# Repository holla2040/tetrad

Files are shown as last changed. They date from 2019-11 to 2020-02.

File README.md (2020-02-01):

# hexad
A 4-axis ESP32 GRBL board 

Board
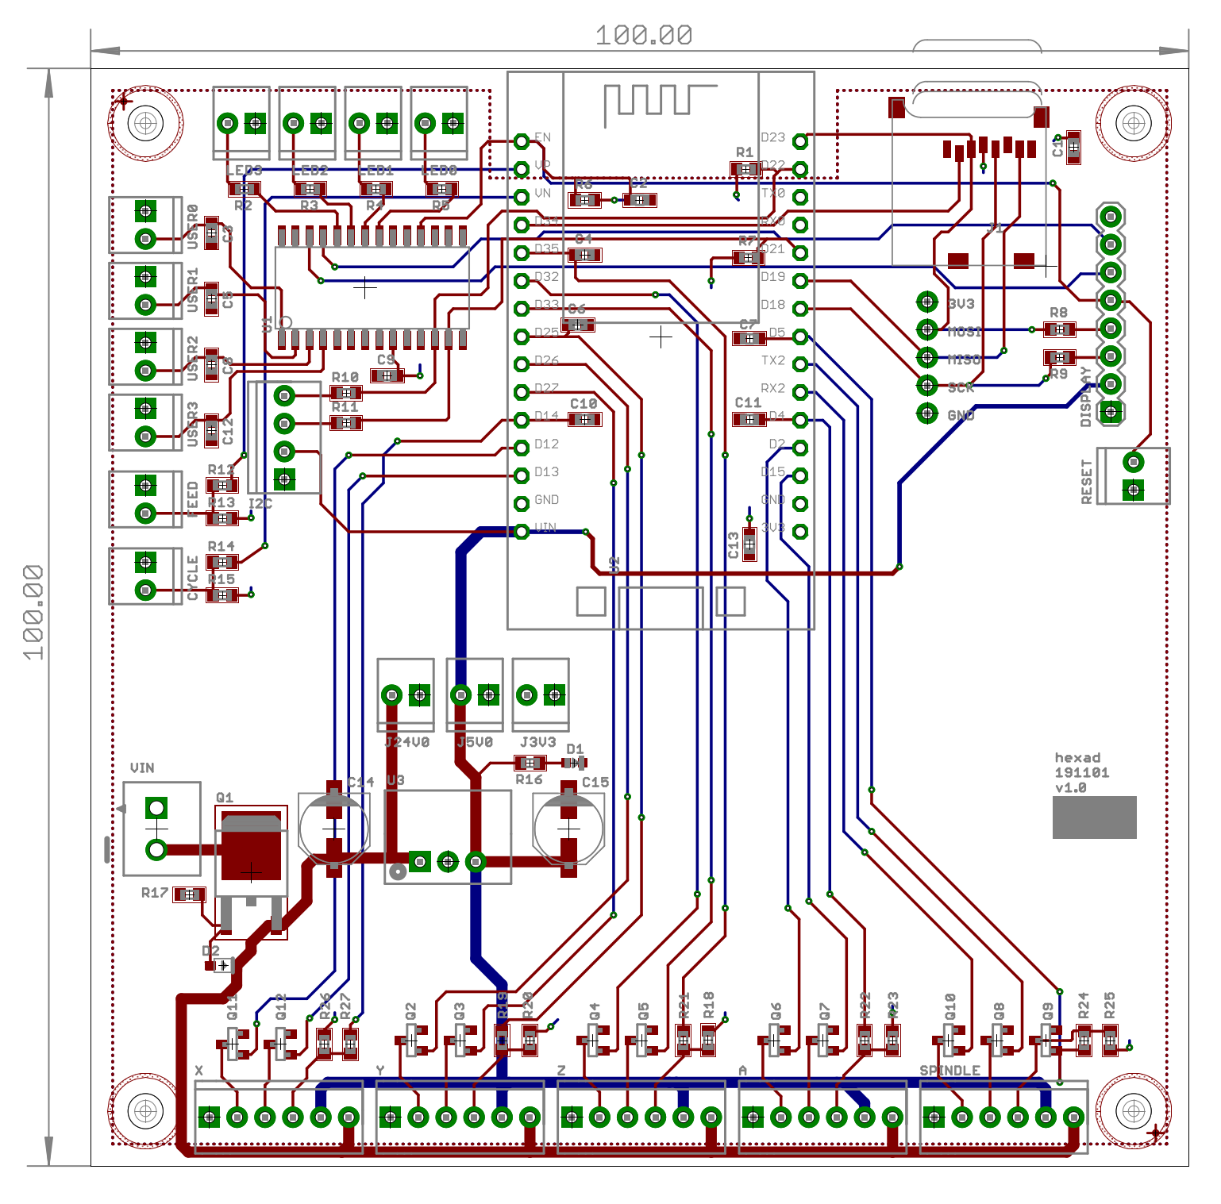
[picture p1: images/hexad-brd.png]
hexad board
    
    [Schematic](board/hexad-sch.pdf)

Requires
    [ESP32SSDP](https://github.com/luc-github/ESP32SSDP)

Compiling
    Select Board "ESP32 Dev Module"
    Flash Size "4MB (32Mb)"
    Partition Scheme "Minimal SPIFFS (1.9MB APP with OTA/190kB SPIFFS)"

    set options, like N_AXIS in config.h

----
Watch the video (https://youtu.be/7fjVDnm6PjQ)

Based on Dring's ESP32 GRBL port
 * [Grbl_ESP32 Development Board Version 3.1](http://www.buildlog.net/blog/2018/11/grbl_esp32-development-board-version-3-1/) 
 * [Source](https://github.com/bdring/Grbl_Esp32)
 * [Schematic](http://www.buildlog.net/blog/wp-content/uploads/2018/10/schm_esp32_cnc_test_v3p1.pdf)
 * [Wiki](https://github.com/bdring/Grbl_Esp32/wiki)

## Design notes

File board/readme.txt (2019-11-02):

This information, board files, assembly instructions and bill of
materials are company confidental.
Not for distribution.

board
    hexad

version
    v1.0

date
    191101

fudicials at
    x,y
    x,y

2 layer description
    2 layer board
        crc component cream
        plc component side silkscreen
        stc component side solder stop mask
        cmp component side copper
        sol solder side copper
        sts solder side solder stop mask
        pls solder side silkscreen
        crs solder cream

        drd drill data
        dri drill info
        gpi gerber info

2 layer stack up sequence
    top     x.cmp
    bottom  x.sol

contact info
    Craig Hollabaugh
    970 690 4911
    craig@hollabaugh.com

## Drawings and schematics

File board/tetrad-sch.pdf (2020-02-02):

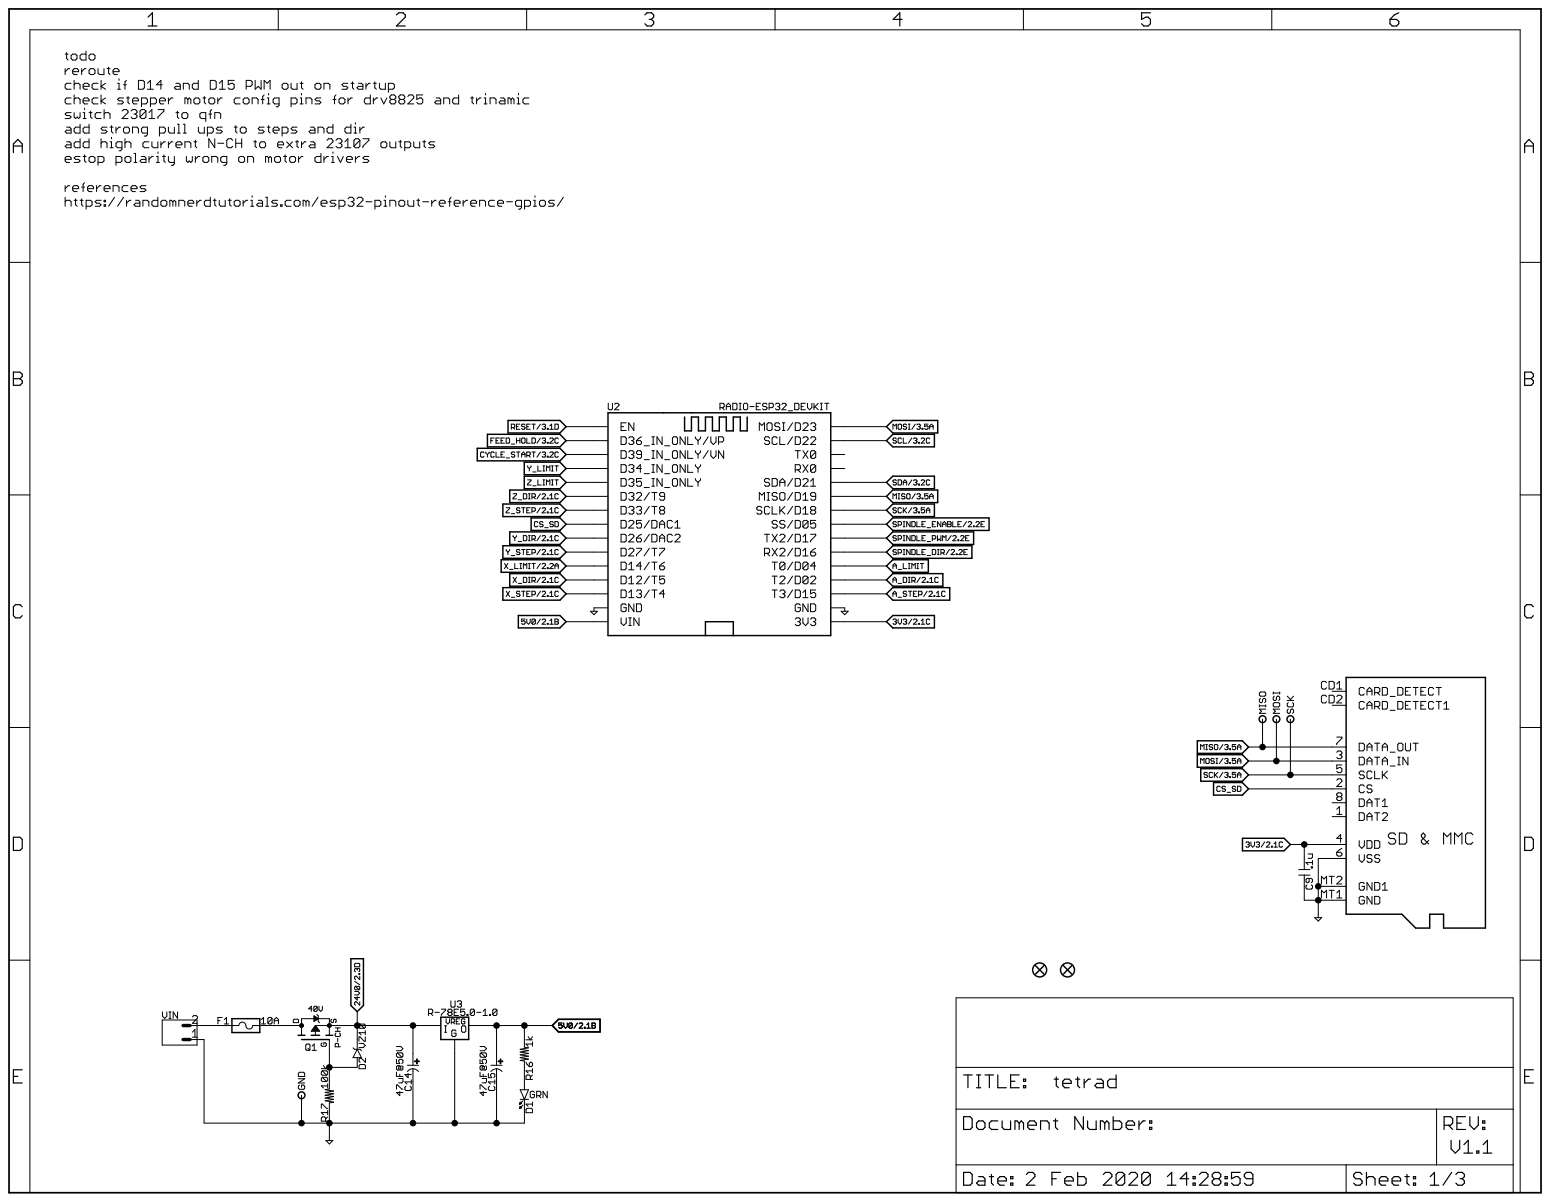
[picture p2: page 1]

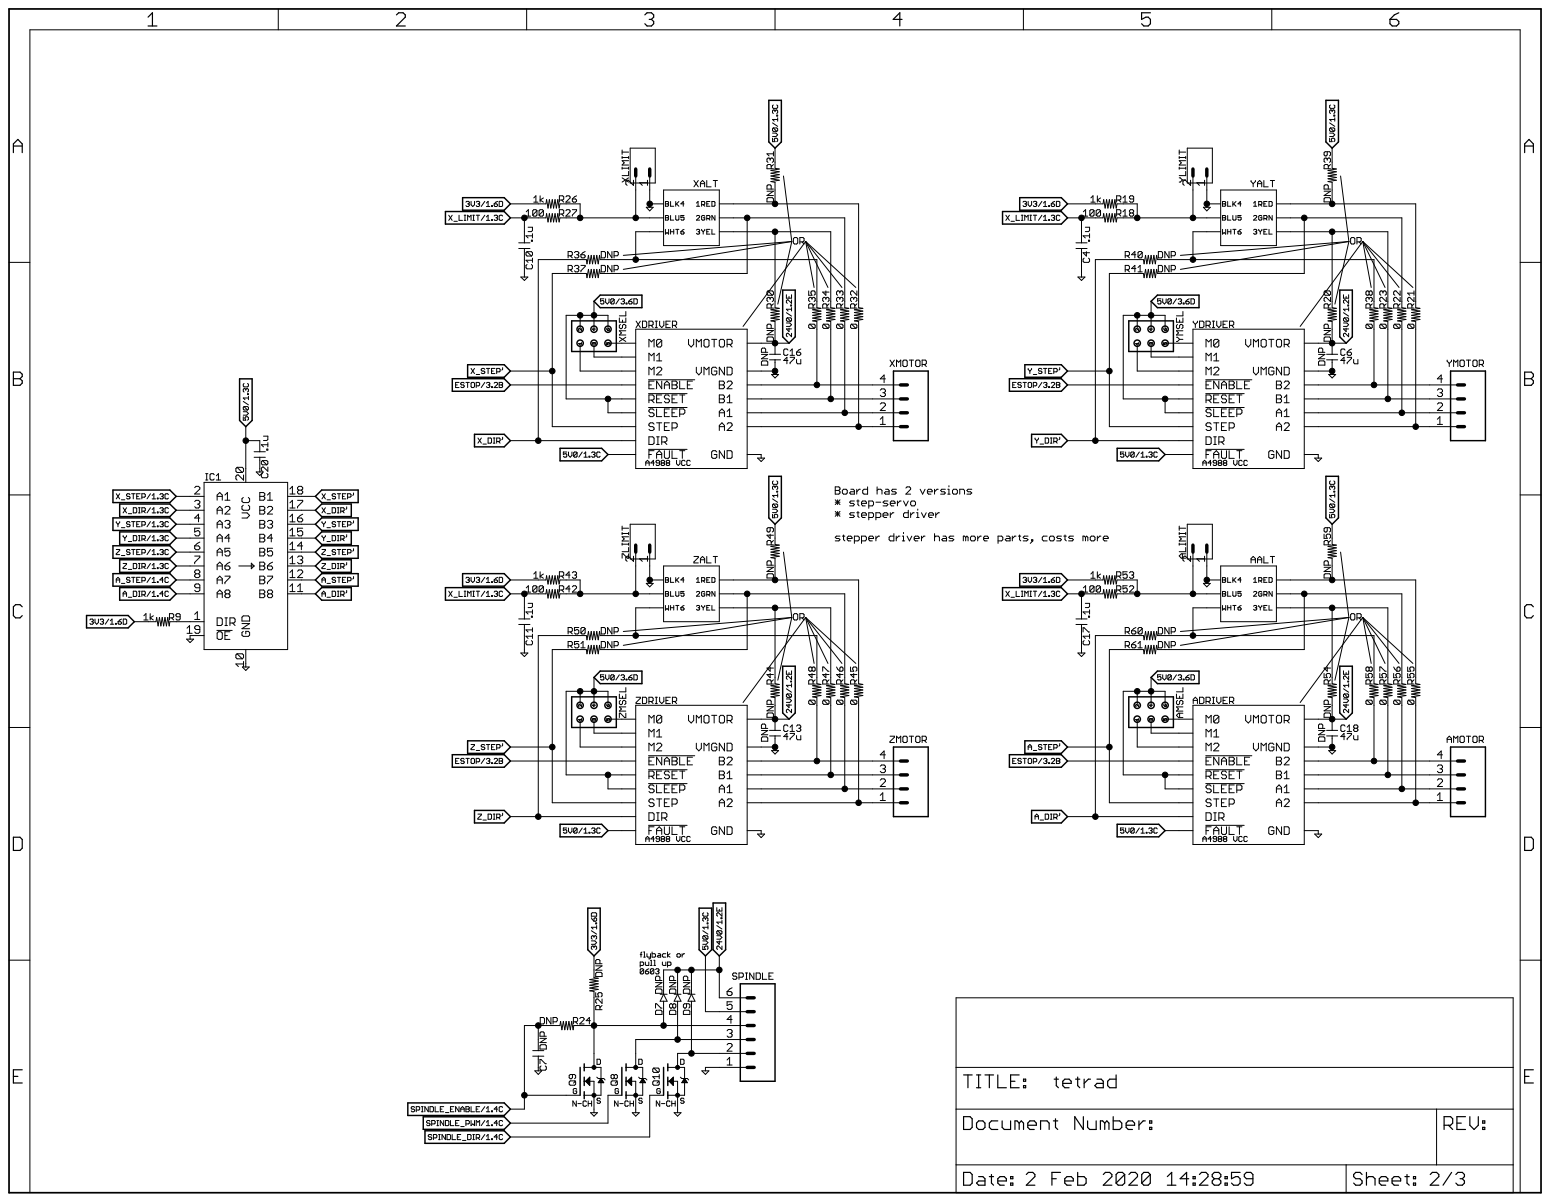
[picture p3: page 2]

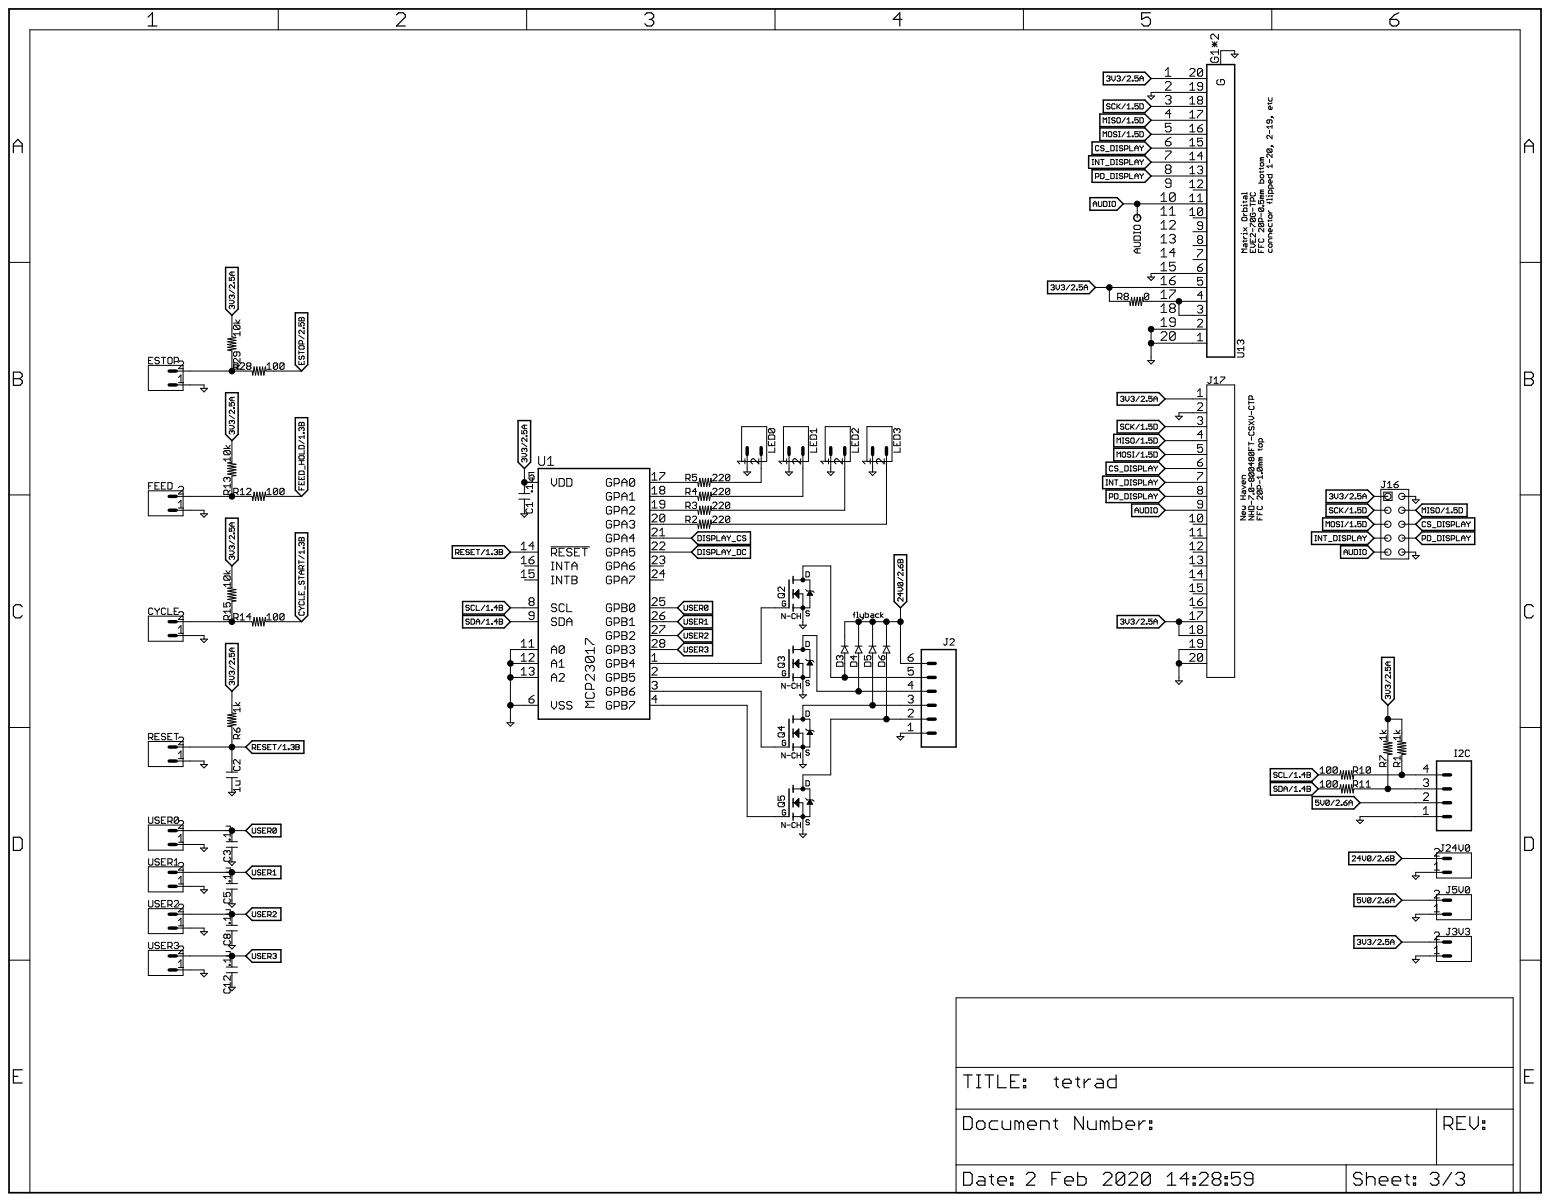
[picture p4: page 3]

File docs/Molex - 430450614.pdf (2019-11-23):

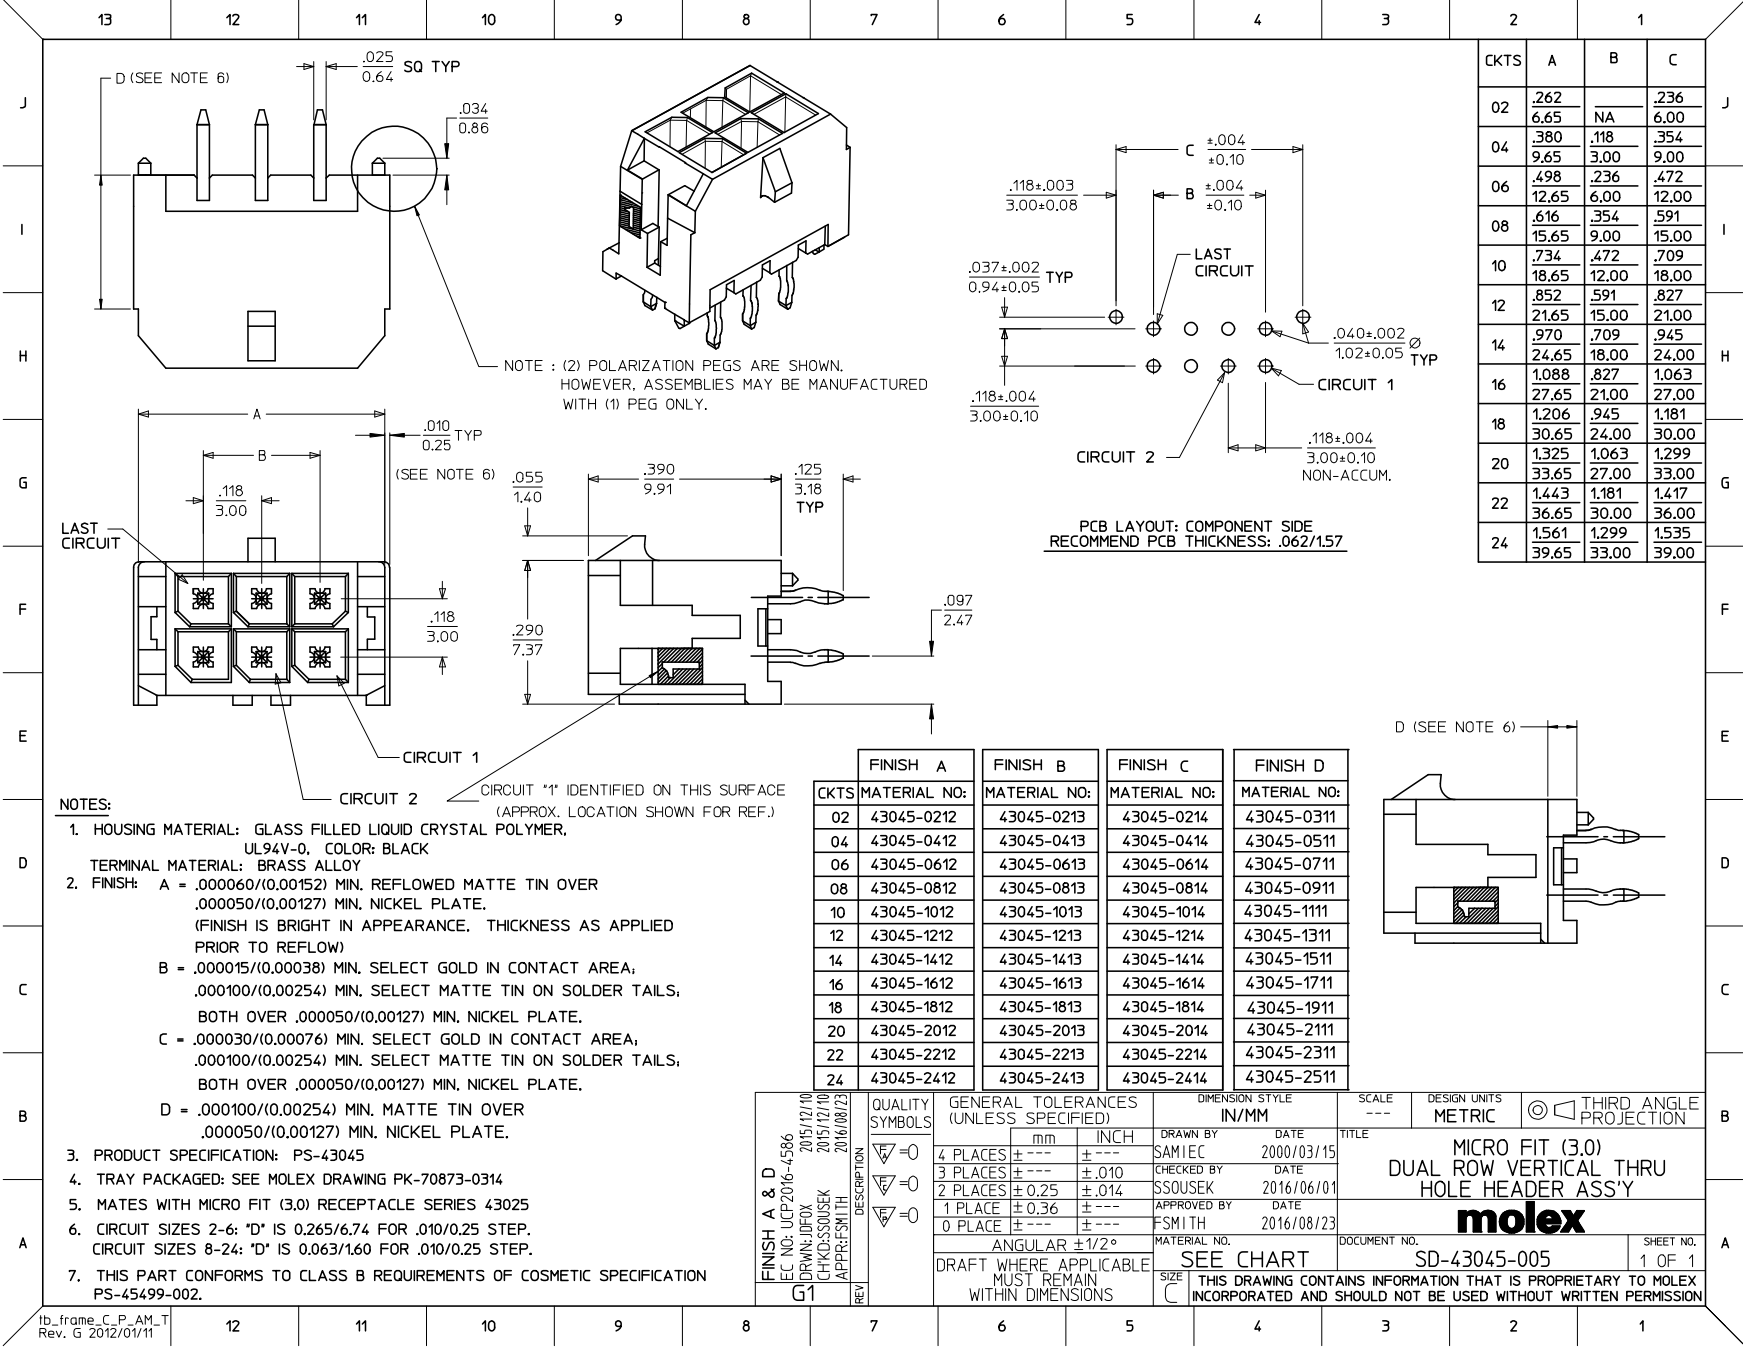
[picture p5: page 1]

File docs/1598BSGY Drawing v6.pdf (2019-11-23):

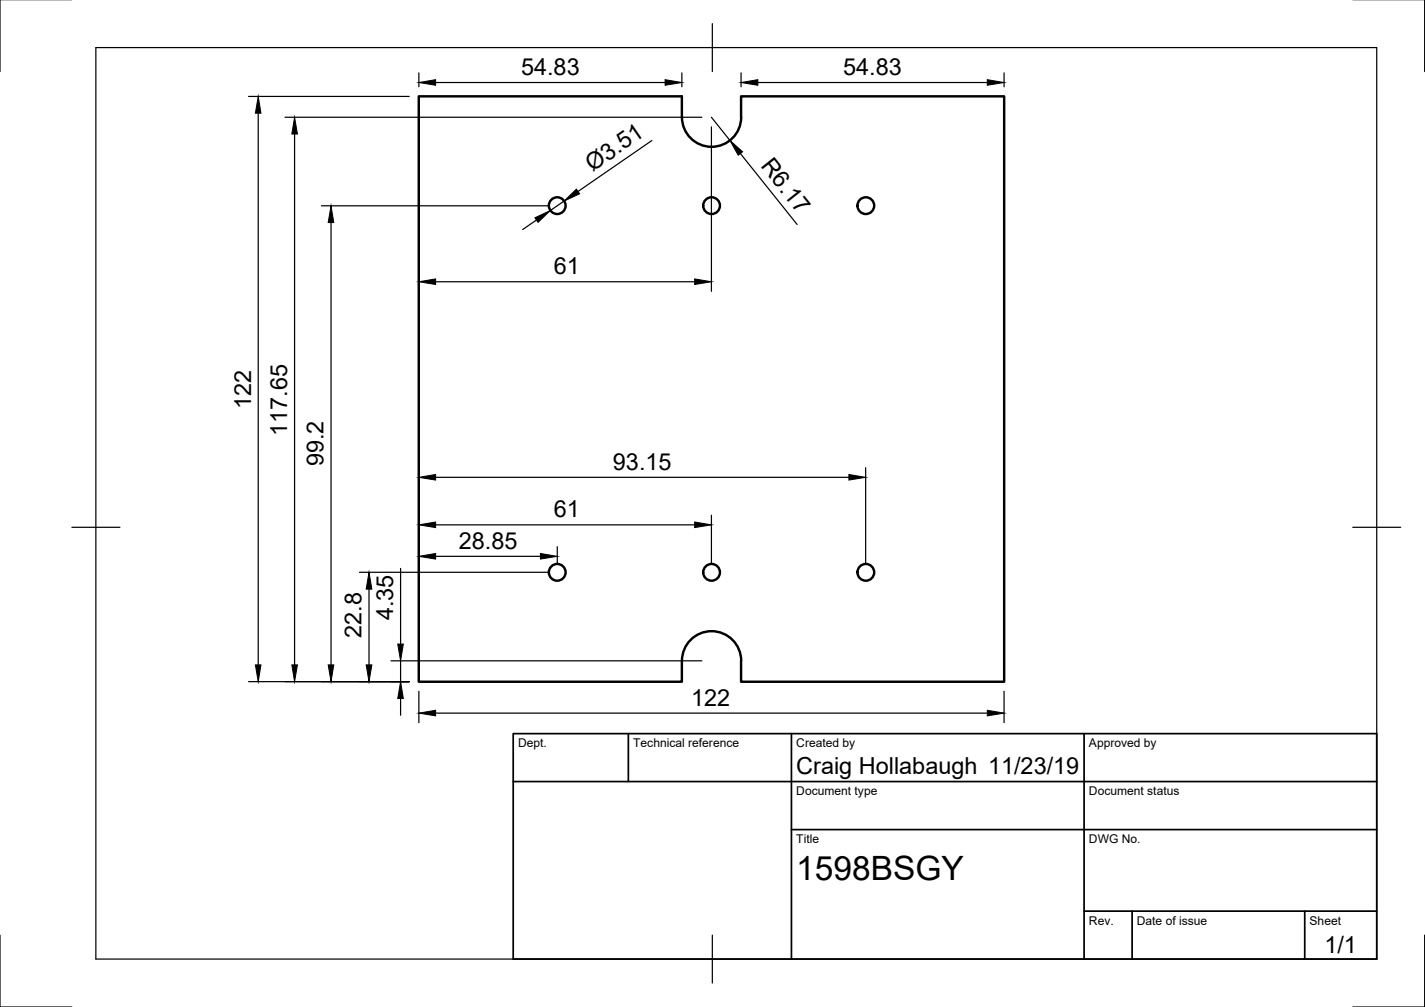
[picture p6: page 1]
Craig Hollabaugh 122

Dept. | Technical reference | Created by 11/23/19 | Approved by

Document type | Document status

Title 1598BSGY | DWG No.

Rev. | Date of issue | Sheet 1/1

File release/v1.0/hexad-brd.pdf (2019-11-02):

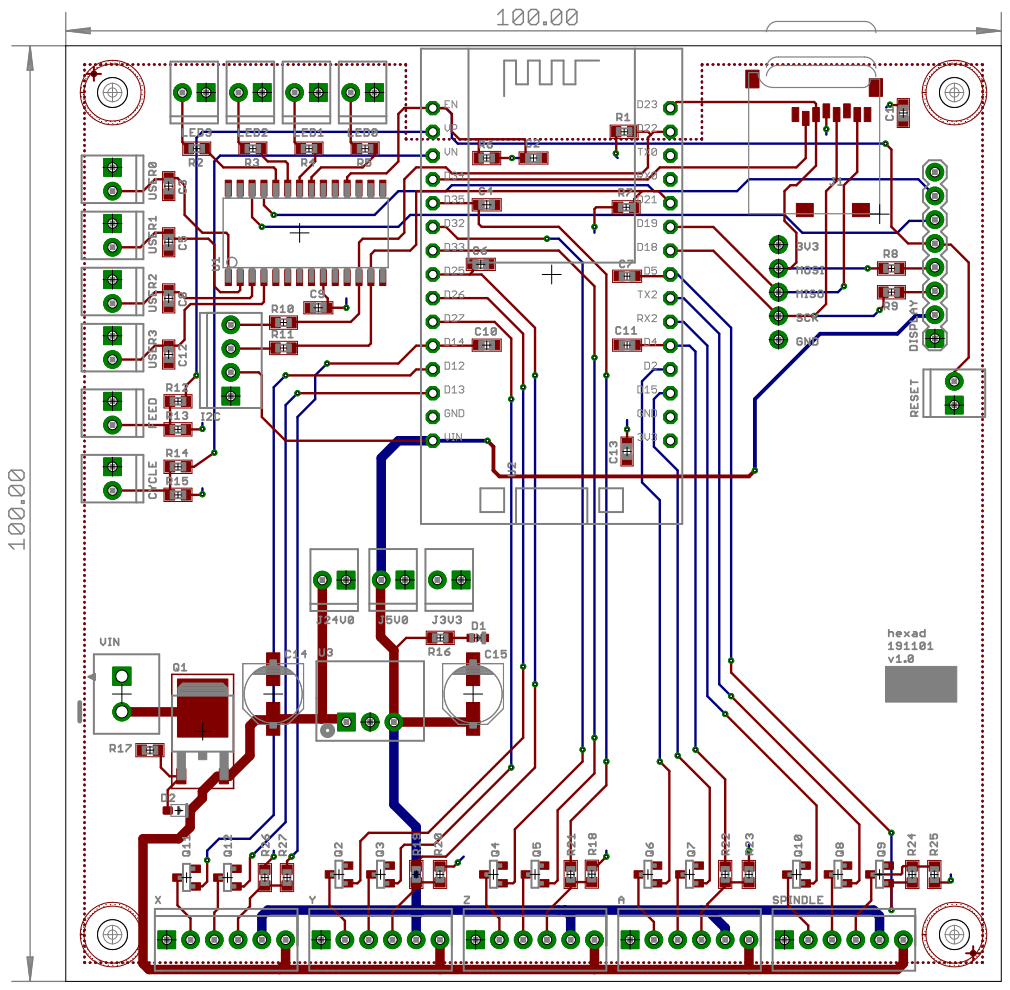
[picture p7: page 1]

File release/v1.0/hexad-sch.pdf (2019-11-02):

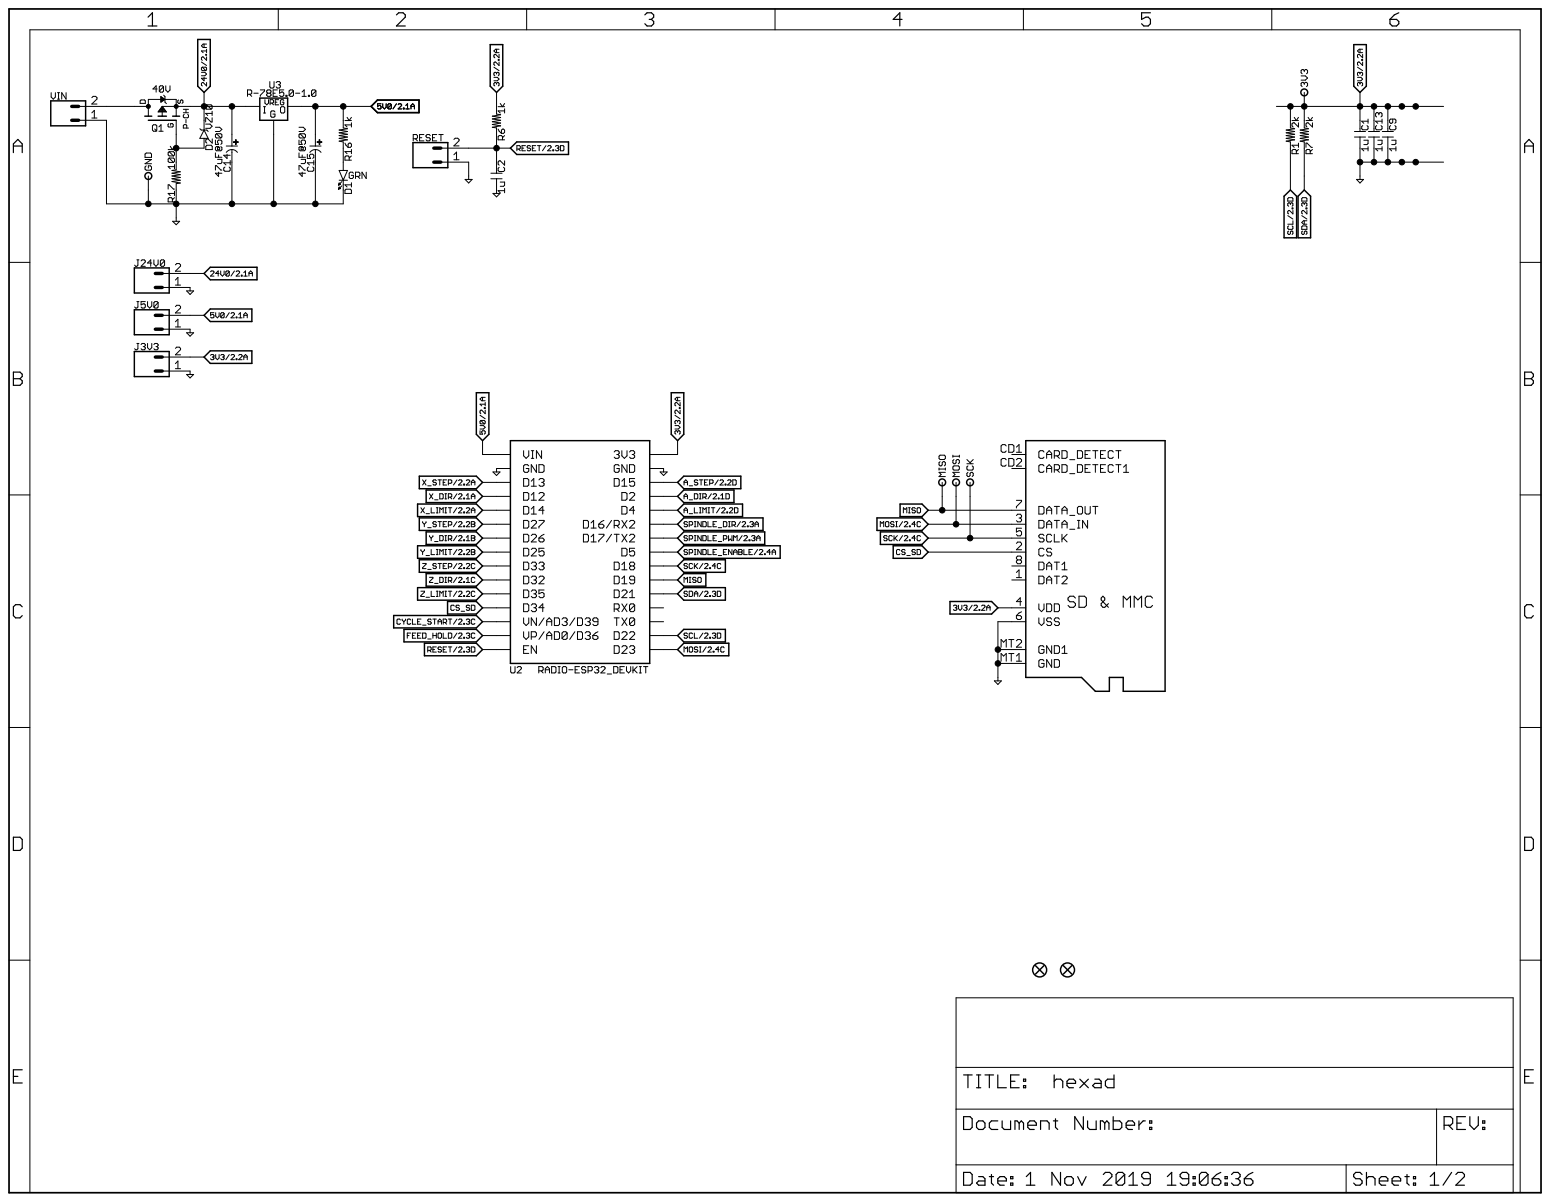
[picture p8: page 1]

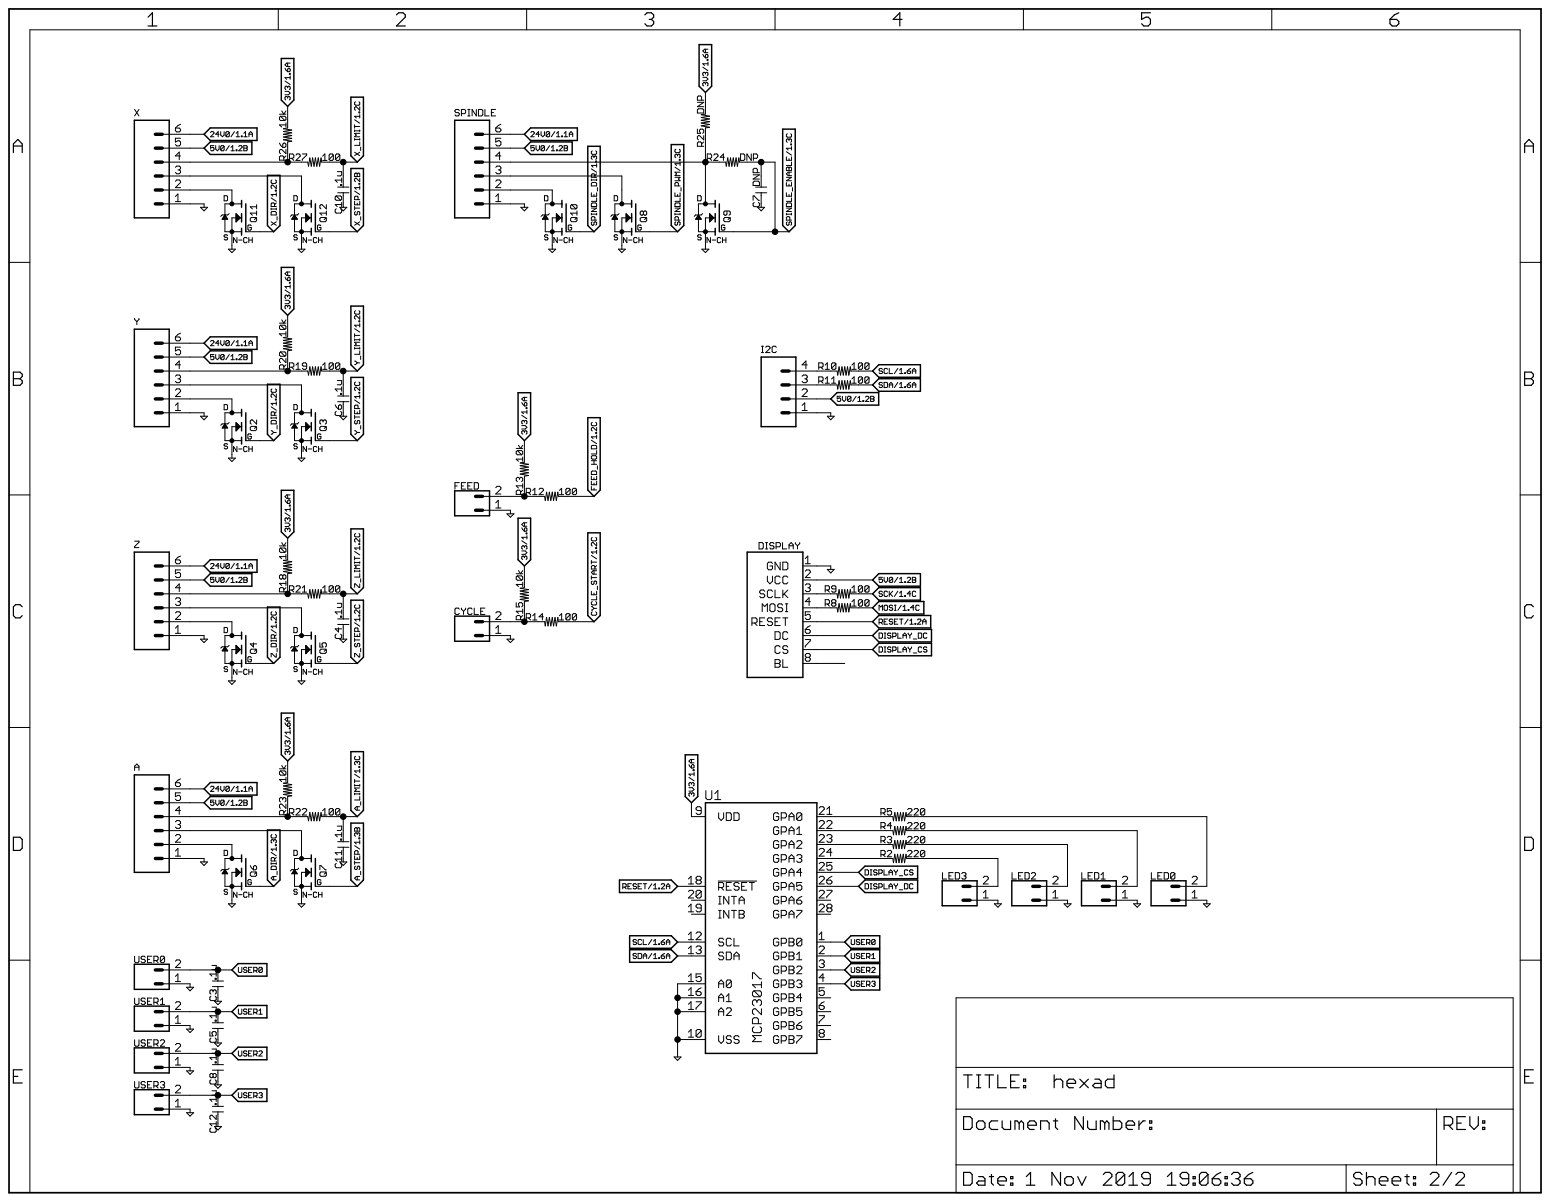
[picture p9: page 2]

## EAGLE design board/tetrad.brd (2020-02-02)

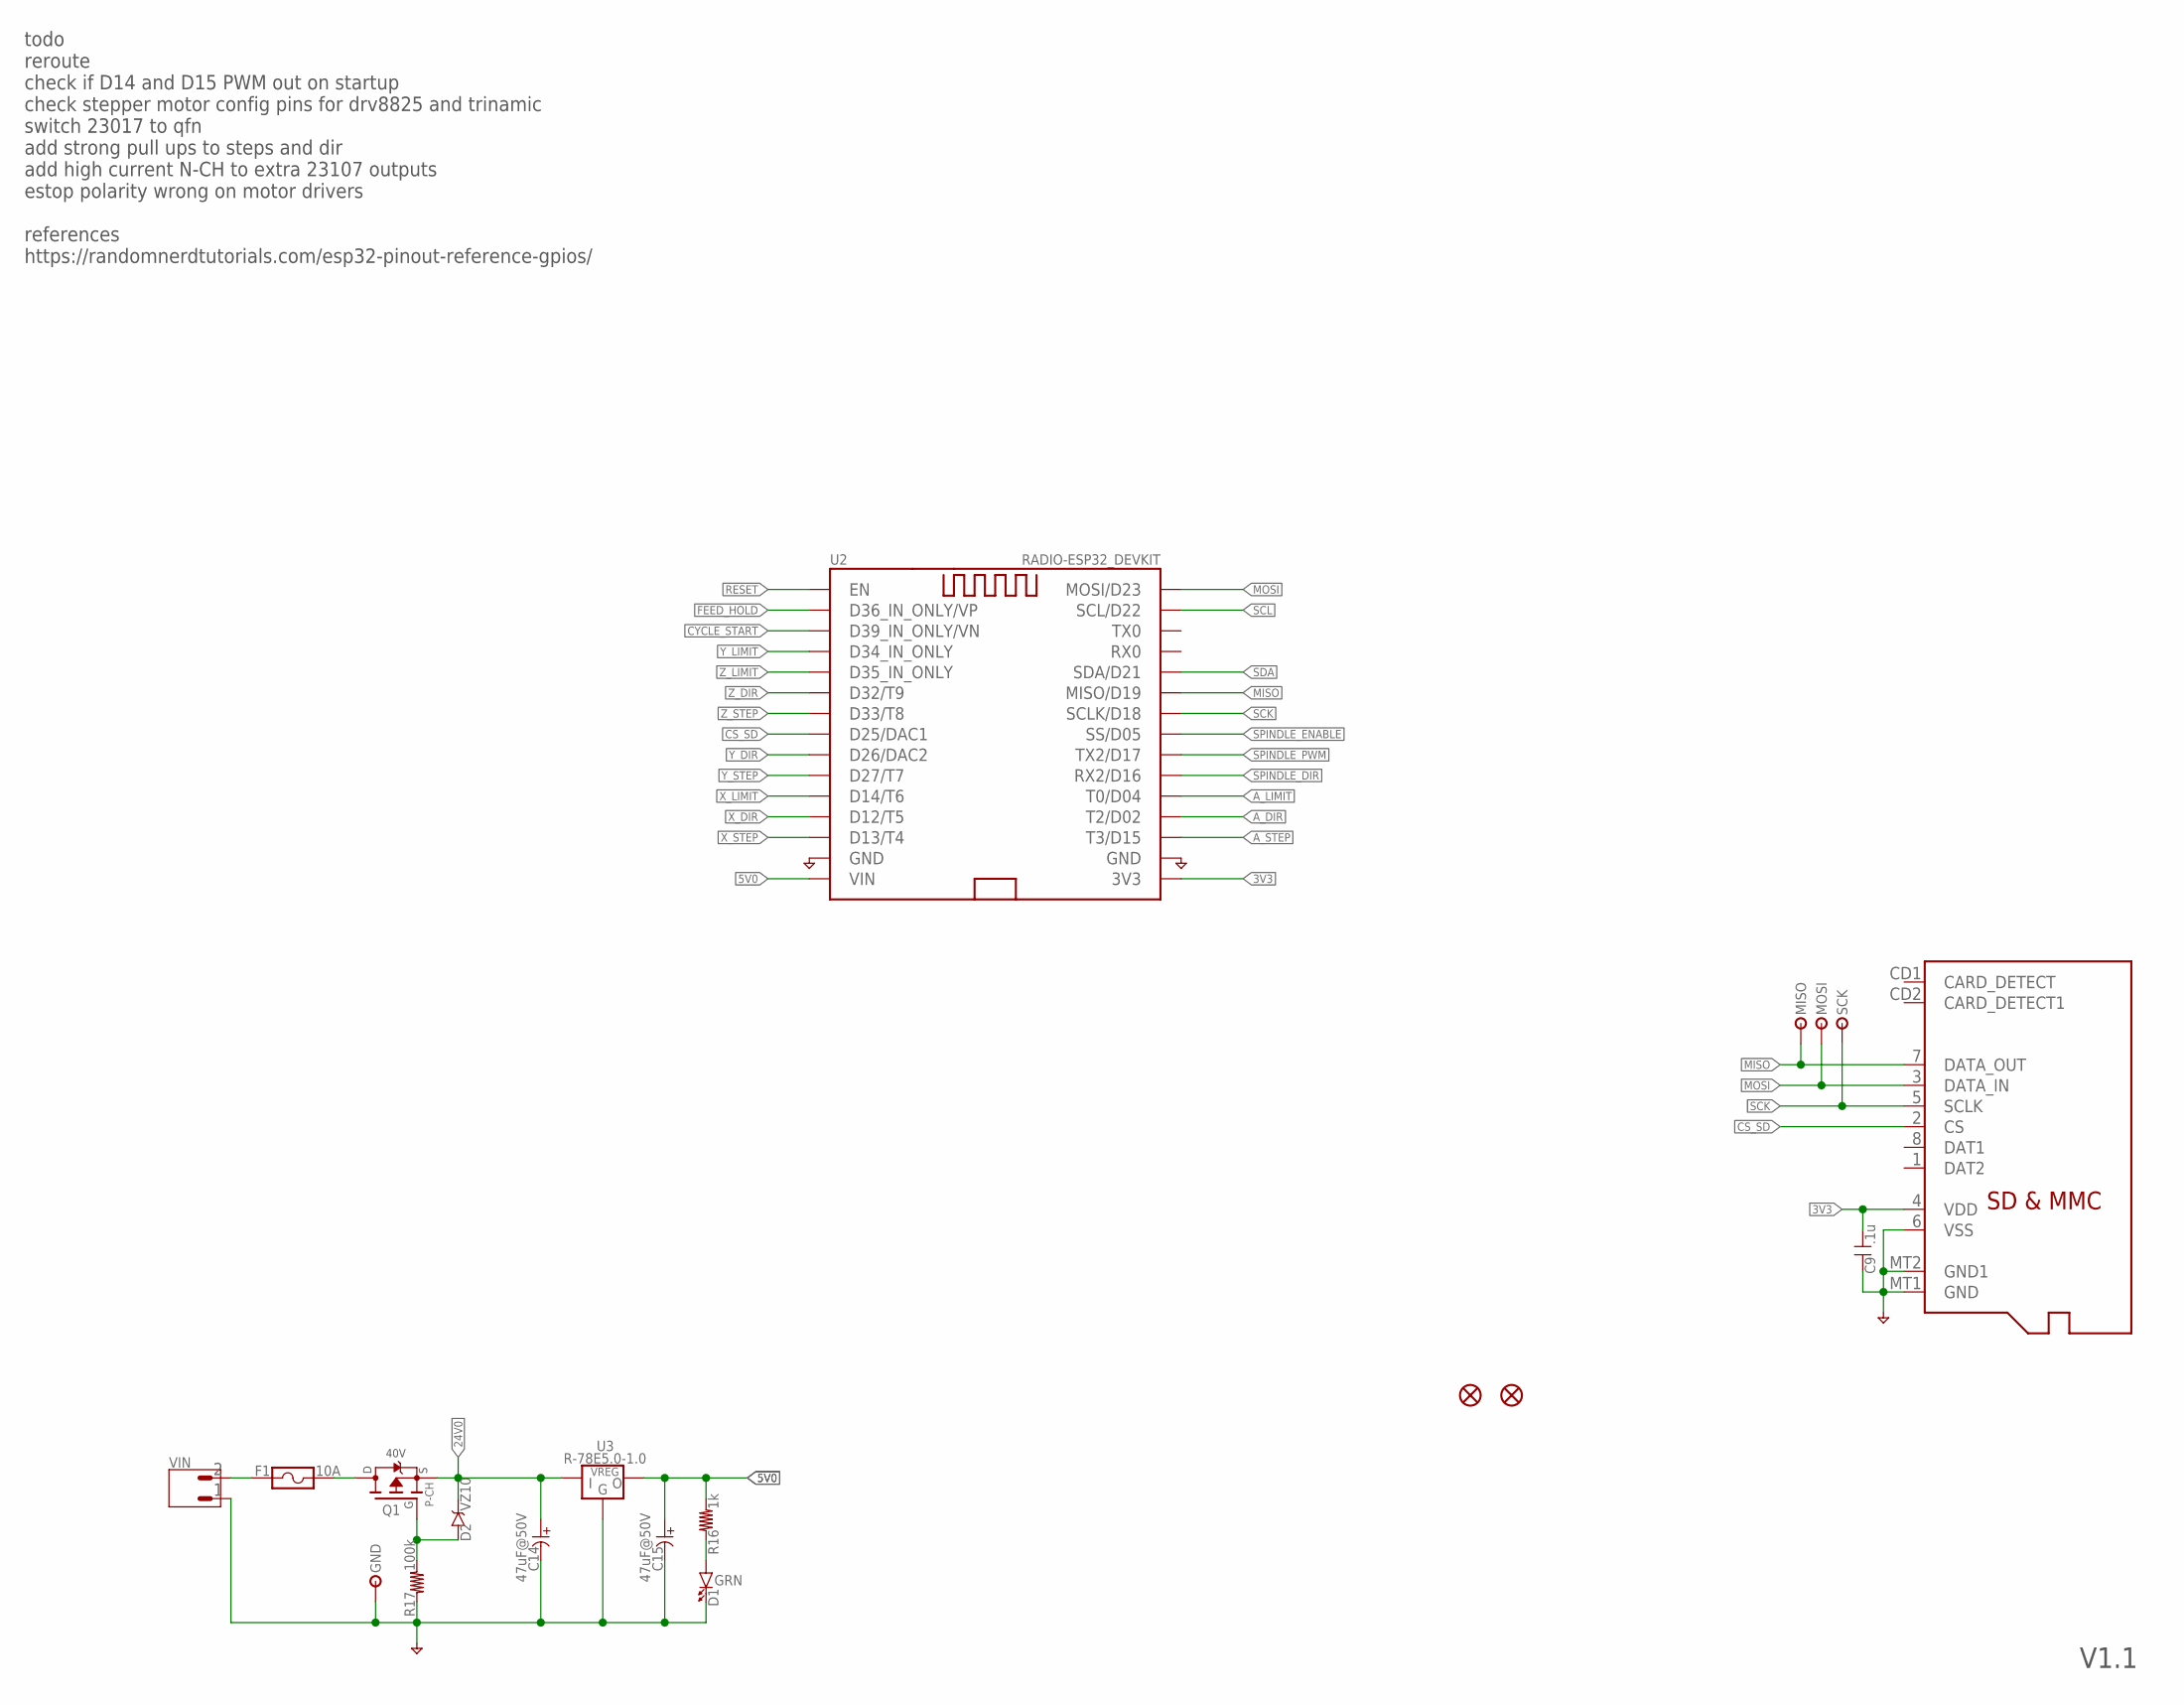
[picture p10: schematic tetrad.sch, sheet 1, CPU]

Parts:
C9: .1u; C-0603
C14, C15: 47uF@50V; C-E-6
D1: GRN; LED-0603
D2: VZ10; D-SOD323
F1: 10A; 3557-2
FID1, FID2: FIDUCIAL-MICRO
GND: TESTPOINTTHRU; TPTHRU
J1: CONN-MICROSD-2908-05WB-MG
MISO: TESTPOINTTHRU; TPTHRU
MOSI: TESTPOINTTHRU; TPTHRU
Q1: FET-PCH-TO252; TO252
R16: 1k; R-0603
R17: 100k; R-0603
SCK: TESTPOINTTHRU; TPTHRU
U2: RADIO-ESP32_DEVKIT; ESP32_DEVKIT
U3: R-78E5.0-1.0; VREG-SIP3
VIN: CONN-02-3.81MM-PLUGIN-SCREW; CONN-3.81MM-KF2EDG-2

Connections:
3V3: C9.1, J1.4 (VDD), U2.3V3; also elsewhere on the board
5V0: C15.+, R16.2, U2.VIN, U3.3 (VOUT); also elsewhere on the board
24V0: C14.+, D2.C, Q1.2 (S), U3.1 (VIN); also elsewhere on the board
A_DIR: U2.D2 (T2/D02); also elsewhere on the board
A_LIMIT: U2.D4 (T0/D04)
A_STEP: U2.D15 (T3/D15); also elsewhere on the board
CS_SD: J1.2 (CS), U2.D25 (D25/DAC1)
CYCLE_START: U2.VN (D39_IN_ONLY/VN); also elsewhere on the board
FEED_HOLD: U2.VP (D36_IN_ONLY/VP); also elsewhere on the board
GND: C9.2, C14.-, C15.-, D1.C, GND.1, J1.6 (VSS), J1.MT1 (GND), J1.MT2 (GND1), R17.1, U2.GND@1 (GND), U2.GND@2 (GND), U3.2 (GND), VIN.1; also elsewhere on the board
MISO: J1.7 (DATA_OUT), MISO.1, U2.D19 (MISO/D19); also elsewhere on the board
MOSI: J1.3 (DATA_IN), MOSI.1, U2.D23 (MOSI/D23); also elsewhere on the board
unnamed: F1.1@1, F1.1@2, VIN.2
unnamed: D2.A, Q1.1 (G), R17.2
unnamed: F1.2@1, F1.2@2, Q1.3 (D)
unnamed: D1.A, R16.1
RESET: U2.EN; also elsewhere on the board
SCK: J1.5 (SCLK), SCK.1, U2.D18 (SCLK/D18); also elsewhere on the board
SCL: U2.D22 (SCL/D22); also elsewhere on the board
SDA: U2.D21 (SDA/D21); also elsewhere on the board
SPINDLE_DIR: U2.RX2 (RX2/D16); also elsewhere on the board
SPINDLE_ENABLE: U2.D5 (SS/D05); also elsewhere on the board
SPINDLE_PWM: U2.TX2 (TX2/D17); also elsewhere on the board
X_DIR: U2.D12 (D12/T5); also elsewhere on the board
X_LIMIT: U2.D14 (D14/T6); also elsewhere on the board
X_STEP: U2.D13 (D13/T4); also elsewhere on the board
Y_DIR: U2.D26 (D26/DAC2); also elsewhere on the board
Y_LIMIT: U2.D34 (D34_IN_ONLY)
Y_STEP: U2.D27 (D27/T7); also elsewhere on the board
Z_DIR: U2.D32 (D32/T9); also elsewhere on the board
Z_LIMIT: U2.D35 (D35_IN_ONLY)
Z_STEP: U2.D33 (D33/T8); also elsewhere on the board

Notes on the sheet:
todo reroute check if D14 and D15 PWM out on startup check stepper motor config pins for drv8825 and trinamic switch 23017 to qfn add strong pull ups to steps and dir add high current N-CH to extra 23107 outputs estop polarity wrong on motor drivers references https://randomnerdtutorials.com/esp32-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
40V
V1.1

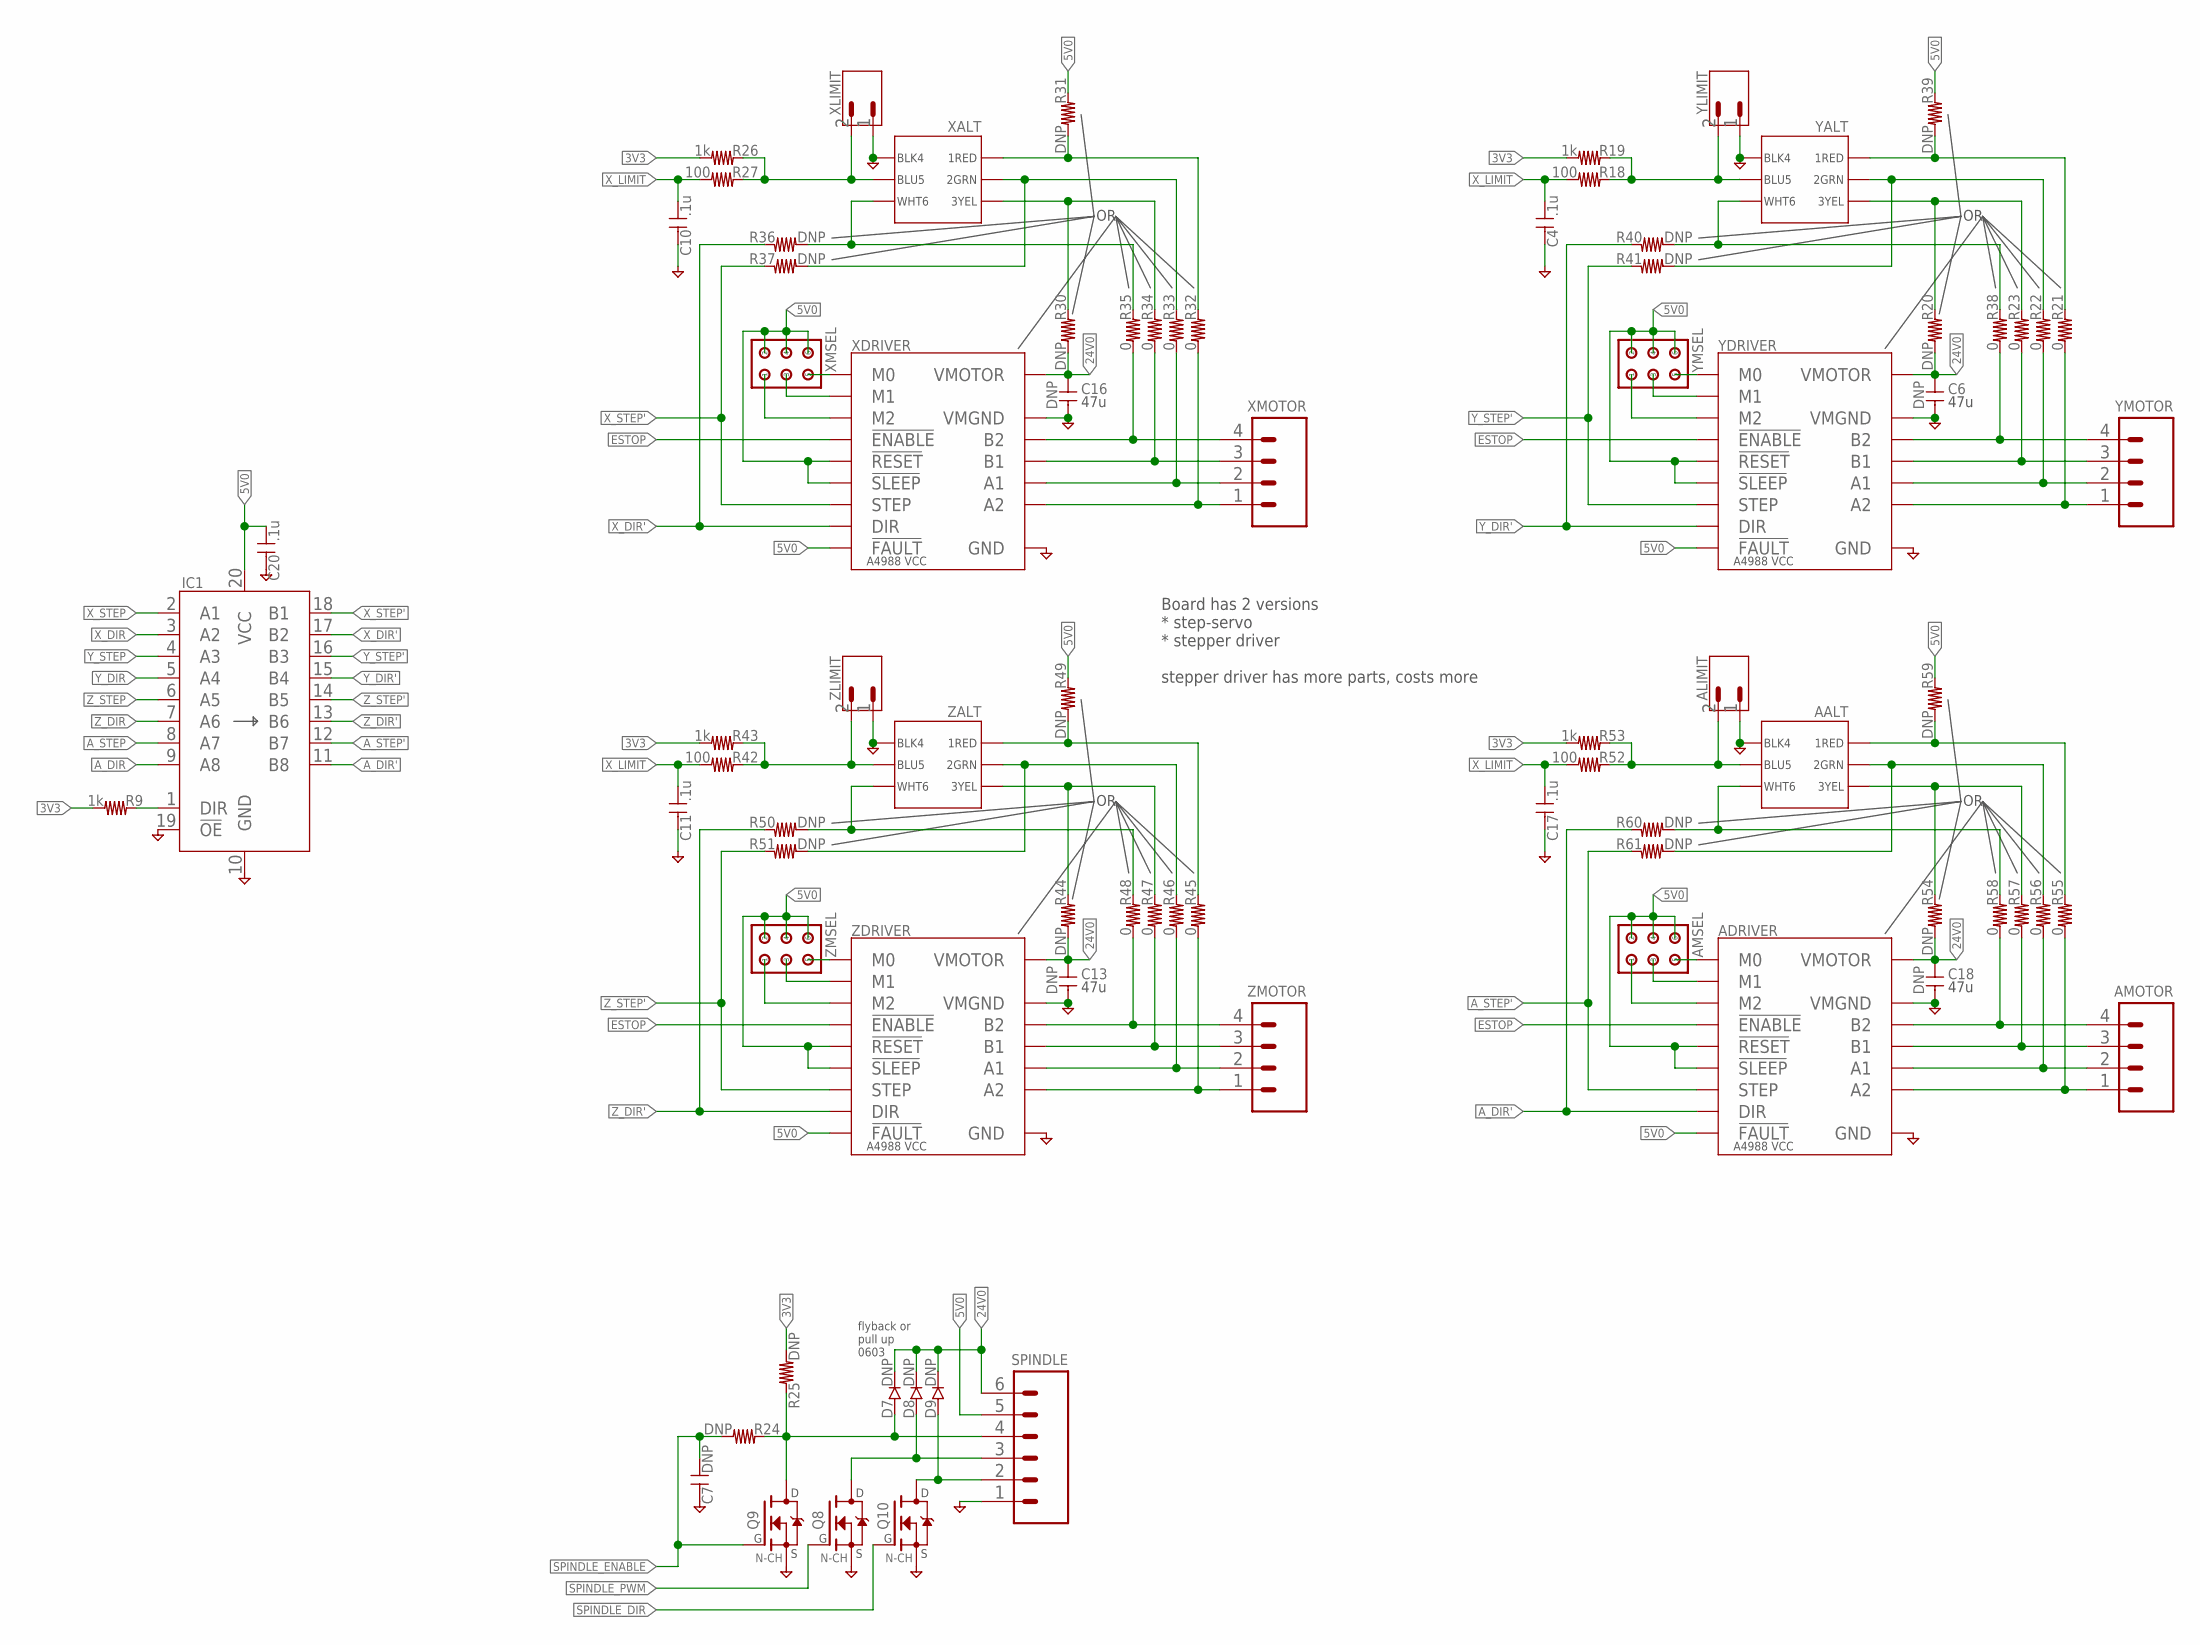
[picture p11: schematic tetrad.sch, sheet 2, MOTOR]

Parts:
AALT: CONN-03X2-MICROFIT-TH-SMD; MOLEX_430450614_430450615
ADRIVER: BOARD-DRV8825-CARRIER-TH-SMD; IC_DRV8825_CARRIER_TH_SMD
ALIMIT: CONN-02-.100-VERT-HEADER; CONN-.100-2
AMOTOR: CONN-04-.100-VERT-HEADER; CONN-.100-4
AMSEL: CONN-03X2-RH; AMPHENOL_95278-101A06LF
C4, C10, C11, C17, C20: .1u; C-0603
C6, C13, C16, C18: DNP; C-1206
C7: DNP; C-0603
D7, D8, D9: DNP; D-SOD523
IC1: 74LS245DW; SO20W
Q8, Q9, Q10: FET-NCH-SOT23; SOT23-3
R9, R19, R26, R43, R53: 1k; R-0603
R18, R27, R42, R52: 100; R-0603
R20, R24, R25, R30, R31, R36, R37, R39, R40, R41, R44, R49, R50, R51, R54, R59, R60, R61: DNP; R-0603
R21, R22, R23, R32, R33, R34, R35, R38, R45, R46, R47, R48, R55, R56, R57, R58: 0; R-0603
SPINDLE: CONN-06-.100-VERT-HEADER; CONN-.100-6
XALT: CONN-03X2-MICROFIT-TH-SMD; MOLEX_430450614_430450615
XDRIVER: BOARD-DRV8825-CARRIER-TH-SMD; IC_DRV8825_CARRIER_TH_SMD
XLIMIT: CONN-02-.100-VERT-HEADER; CONN-.100-2
XMOTOR: CONN-04-.100-VERT-HEADER; CONN-.100-4
XMSEL: CONN-03X2-RH; AMPHENOL_95278-101A06LF
YALT: CONN-03X2-MICROFIT-TH-SMD; MOLEX_430450614_430450615
YDRIVER: BOARD-DRV8825-CARRIER-TH-SMD; IC_DRV8825_CARRIER_TH_SMD
YLIMIT: CONN-02-.100-VERT-HEADER; CONN-.100-2
YMOTOR: CONN-04-.100-VERT-HEADER; CONN-.100-4
YMSEL: CONN-03X2-RH; AMPHENOL_95278-101A06LF
ZALT: CONN-03X2-MICROFIT-TH-SMD; MOLEX_430450614_430450615
ZDRIVER: BOARD-DRV8825-CARRIER-TH-SMD; IC_DRV8825_CARRIER_TH_SMD
ZLIMIT: CONN-02-.100-VERT-HEADER; CONN-.100-2
ZMOTOR: CONN-04-.100-VERT-HEADER; CONN-.100-4
ZMSEL: CONN-03X2-RH; AMPHENOL_95278-101A06LF

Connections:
3V3: R9.2, R19.2, R25.2, R26.2, R43.2, R53.2; also elsewhere on the board
5V0: ADRIVER.5 (!RESET), ADRIVER.5_ (!RESET), ADRIVER.6 (!SLEEP), ADRIVER.6_ (!SLEEP), ADRIVER.10 (!FAULT), ADRIVER.10_ (!FAULT), AMSEL.2, AMSEL.4, AMSEL.6, C20.1, IC1.20 (VCC), R31.1, R39.1, R49.1, R59.1, SPINDLE.5, XDRIVER.5 (!RESET), XDRIVER.5_ (!RESET), XDRIVER.6 (!SLEEP), XDRIVER.6_ (!SLEEP), XDRIVER.10 (!FAULT), XDRIVER.10_ (!FAULT), XMSEL.2, XMSEL.4, XMSEL.6, YDRIVER.5 (!RESET), YDRIVER.5_ (!RESET), YDRIVER.6 (!SLEEP), YDRIVER.6_ (!SLEEP), YDRIVER.10 (!FAULT), YDRIVER.10_ (!FAULT), YMSEL.2, YMSEL.4, YMSEL.6, ZDRIVER.5 (!RESET), ZDRIVER.5_ (!RESET), ZDRIVER.6 (!SLEEP), ZDRIVER.6_ (!SLEEP), ZDRIVER.10 (!FAULT), ZDRIVER.10_ (!FAULT), ZMSEL.2, ZMSEL.4, ZMSEL.6; also elsewhere on the board
24V0: ADRIVER.16 (VMOTOR), ADRIVER.16_ (VMOTOR), C6.1, C13.1, C16.1, C18.1, D7.C, D8.C, D9.C, R20.2, R30.2, R44.2, R54.2, SPINDLE.6, XDRIVER.16 (VMOTOR), XDRIVER.16_ (VMOTOR), YDRIVER.16 (VMOTOR), YDRIVER.16_ (VMOTOR), ZDRIVER.16 (VMOTOR), ZDRIVER.16_ (VMOTOR); also elsewhere on the board
A_DIR: IC1.9 (A8); also elsewhere on the board
A_DIR': ADRIVER.8 (DIR), ADRIVER.8_ (DIR), IC1.11 (B8), R60.1
A_STEP: IC1.8 (A7); also elsewhere on the board
A_STEP': ADRIVER.7 (STEP), ADRIVER.7_ (STEP), IC1.12 (B7), R61.1
ESTOP: ADRIVER.1 (!ENABLE), ADRIVER.1_ (!ENABLE), XDRIVER.1 (!ENABLE), XDRIVER.1_ (!ENABLE), YDRIVER.1 (!ENABLE), YDRIVER.1_ (!ENABLE), ZDRIVER.1 (!ENABLE), ZDRIVER.1_ (!ENABLE); also elsewhere on the board
GND: AALT.4, AALT.4_ (4), ADRIVER.9 (GND), ADRIVER.9_ (GND), ADRIVER.15 (VMGND), ADRIVER.15_ (VMGND), ALIMIT.1, C4.2, C6.2, C7.2, C10.2, C11.2, C13.2, C16.2, C17.2, C18.2, C20.2, IC1.10 (GND), IC1.19 (!OE), Q8.2 (S), Q9.2 (S), Q10.2 (S), SPINDLE.1, XALT.4, XALT.4_ (4), XDRIVER.9 (GND), XDRIVER.9_ (GND), XDRIVER.15 (VMGND), XDRIVER.15_ (VMGND), XLIMIT.1, YALT.4, YALT.4_ (4), YDRIVER.9 (GND), YDRIVER.9_ (GND), YDRIVER.15 (VMGND), YDRIVER.15_ (VMGND), YLIMIT.1, ZALT.4, ZALT.4_ (4), ZDRIVER.9 (GND), ZDRIVER.9_ (GND), ZDRIVER.15 (VMGND), ZDRIVER.15_ (VMGND), ZLIMIT.1; also elsewhere on the board
unnamed: R30.1, R34.1, XALT.3, XALT.3_ (3)
unnamed: IC1.1 (DIR), R9.1
unnamed: R31.2, R32.1, XALT.1, XALT.1_ (1)
unnamed: R21.2, YDRIVER.11 (A2), YDRIVER.11_ (A2), YMOTOR.1
unnamed: YDRIVER.2 (M0), YDRIVER.2_ (M0), YMSEL.5
unnamed: YDRIVER.3 (M1), YDRIVER.3_ (M1), YMSEL.3
unnamed: YDRIVER.4 (M2), YDRIVER.4_ (M2), YMSEL.1
unnamed: R22.2, YDRIVER.12 (A1), YDRIVER.12_ (A1), YMOTOR.2
unnamed: R23.2, YDRIVER.13 (B1), YDRIVER.13_ (B1), YMOTOR.3
unnamed: D7.A, Q9.3 (D), R24.1, R25.1, SPINDLE.4
unnamed: D9.A, Q10.3 (D), SPINDLE.2
unnamed: R38.2, YDRIVER.14 (B2), YDRIVER.14_ (B2), YMOTOR.4
unnamed: R32.2, XDRIVER.11 (A2), XDRIVER.11_ (A2), XMOTOR.1
unnamed: R18.1, R19.1, YALT.5, YALT.5_ (5), YLIMIT.2
unnamed: XDRIVER.2 (M0), XDRIVER.2_ (M0), XMSEL.5
unnamed: XDRIVER.3 (M1), XDRIVER.3_ (M1), XMSEL.3
unnamed: XDRIVER.4 (M2), XDRIVER.4_ (M2), XMSEL.1
unnamed: R38.1, R40.2, YALT.6, YALT.6_ (6)
unnamed: R21.1, R39.2, YALT.1, YALT.1_ (1)
unnamed: R20.1, R23.1, YALT.3, YALT.3_ (3)
unnamed: R45.2, ZDRIVER.11 (A2), ZDRIVER.11_ (A2), ZMOTOR.1
unnamed: ZDRIVER.2 (M0), ZDRIVER.2_ (M0), ZMSEL.5
unnamed: ZDRIVER.3 (M1), ZDRIVER.3_ (M1), ZMSEL.3
unnamed: ZDRIVER.4 (M2), ZDRIVER.4_ (M2), ZMSEL.1
unnamed: R46.2, ZDRIVER.12 (A1), ZDRIVER.12_ (A1), ZMOTOR.2
unnamed: R47.2, ZDRIVER.13 (B1), ZDRIVER.13_ (B1), ZMOTOR.3
unnamed: R48.2, ZDRIVER.14 (B2), ZDRIVER.14_ (B2), ZMOTOR.4
unnamed: R42.1, R43.1, ZALT.5, ZALT.5_ (5), ZLIMIT.2
unnamed: R48.1, R50.2, ZALT.6, ZALT.6_ (6)
unnamed: R45.1, R49.2, ZALT.1, ZALT.1_ (1)
unnamed: R44.1, R47.1, ZALT.3, ZALT.3_ (3)
unnamed: ADRIVER.11 (A2), ADRIVER.11_ (A2), AMOTOR.1, R55.2
unnamed: R35.2, XDRIVER.14 (B2), XDRIVER.14_ (B2), XMOTOR.4
unnamed: R26.1, R27.1, XALT.5, XALT.5_ (5), XLIMIT.2
unnamed: ADRIVER.2 (M0), ADRIVER.2_ (M0), AMSEL.5
unnamed: R35.1, R36.2, XALT.6, XALT.6_ (6)
unnamed: ADRIVER.3 (M1), ADRIVER.3_ (M1), AMSEL.3
unnamed: R33.2, XDRIVER.12 (A1), XDRIVER.12_ (A1), XMOTOR.2
unnamed: R34.2, XDRIVER.13 (B1), XDRIVER.13_ (B1), XMOTOR.3
unnamed: ADRIVER.4 (M2), ADRIVER.4_ (M2), AMSEL.1
unnamed: ADRIVER.12 (A1), ADRIVER.12_ (A1), AMOTOR.2, R56.2
unnamed: ADRIVER.13 (B1), ADRIVER.13_ (B1), AMOTOR.3, R57.2
unnamed: ADRIVER.14 (B2), ADRIVER.14_ (B2), AMOTOR.4, R58.2
unnamed: AALT.5, AALT.5_ (5), ALIMIT.2, R52.1, R53.1
unnamed: AALT.6, AALT.6_ (6), R58.1, R60.2
unnamed: AALT.1, AALT.1_ (1), R55.1, R59.2
unnamed: AALT.3, AALT.3_ (3), R54.1, R57.1
SPINDLE_DIR: Q10.1 (G); also elsewhere on the board
SPINDLE_ENABLE: C7.1, Q9.1 (G), R24.2; also elsewhere on the board
SPINDLE_PWM: Q8.1 (G); also elsewhere on the board
X_DIR: IC1.3 (A2); also elsewhere on the board
X_DIR': IC1.17 (B2), R36.1, XDRIVER.8 (DIR), XDRIVER.8_ (DIR)
X_LIMIT: C4.1, C10.1, C11.1, C17.1, R18.2, R27.2, R42.2, R52.2; also elsewhere on the board
X_STEP: IC1.2 (A1); also elsewhere on the board
X_STEP': IC1.18 (B1), R22.1, R33.1, R37.1, R37.2, R41.2, R46.1, R51.2, XALT.2, XALT.2_ (2), XDRIVER.7 (STEP), XDRIVER.7_ (STEP), YALT.2, YALT.2_ (2), ZALT.2, ZALT.2_ (2)
X_STEP'1: AALT.2, AALT.2_ (2), R56.1, R61.2
X_STEP_5V4: D8.A, Q8.3 (D), SPINDLE.3
Y_DIR: IC1.5 (A4); also elsewhere on the board
Y_DIR': IC1.15 (B4), R40.1, YDRIVER.8 (DIR), YDRIVER.8_ (DIR)
Y_STEP: IC1.4 (A3); also elsewhere on the board
Y_STEP': IC1.16 (B3), R41.1, YDRIVER.7 (STEP), YDRIVER.7_ (STEP)
Z_DIR: IC1.7 (A6); also elsewhere on the board
Z_DIR': IC1.13 (B6), R50.1, ZDRIVER.8 (DIR), ZDRIVER.8_ (DIR)
Z_STEP: IC1.6 (A5); also elsewhere on the board
Z_STEP': IC1.14 (B5), R51.1, ZDRIVER.7 (STEP), ZDRIVER.7_ (STEP)

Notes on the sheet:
47u
flyback or pull up 0603
Board has 2 versions * step-servo * stepper driver stepper driver has more parts, costs more

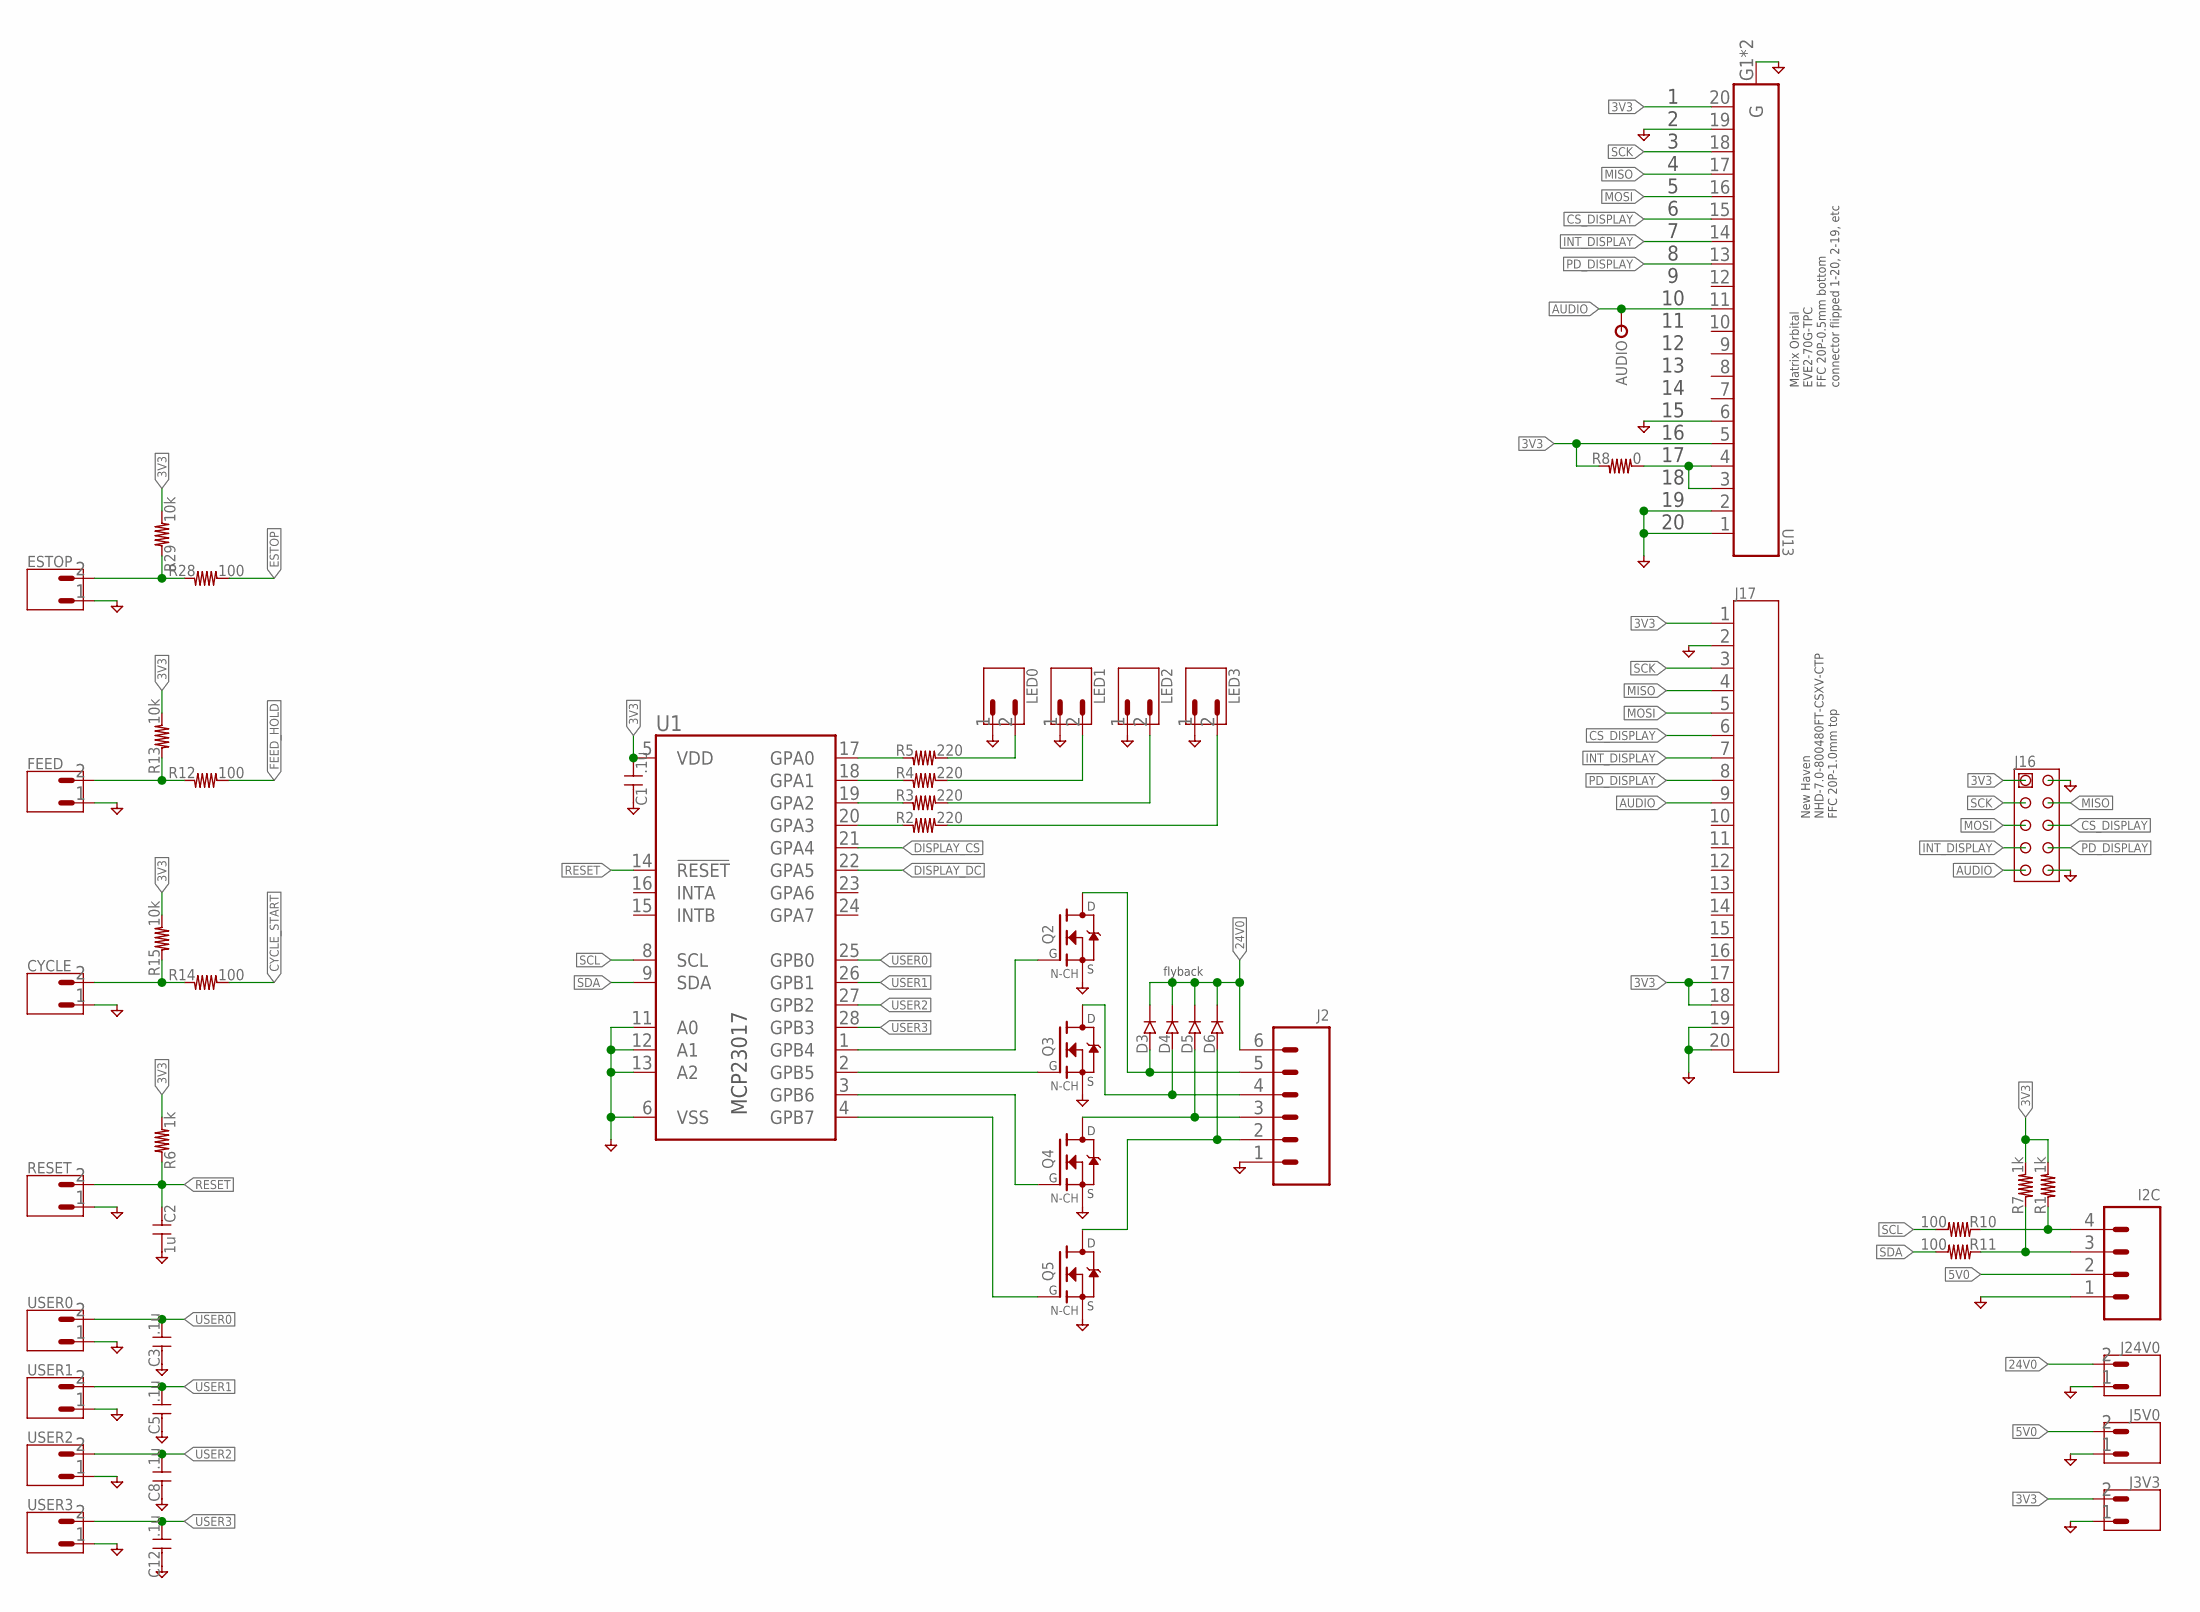
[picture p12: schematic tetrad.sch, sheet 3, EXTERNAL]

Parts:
AUDIO: TESTPOINTTHRU; TPTHRU
C1, C3, C5, C8, C12: .1u; C-0603
C2: 1u; C-0603
CYCLE: CONN-02-.100-VERT-HEADER; CONN-.100-2
D3, D4, D5, D6: DIODE-0603-SOD523; D-SOD523
ESTOP: CONN-02-.100-VERT-HEADER; CONN-.100-2
FEED: CONN-02-.100-VERT-HEADER; CONN-.100-2
I2C: CONN-04-.100-VERT-HEADER; CONN-.100-4
J2: CONN-06-3.81MM-PLUGIN-SCREW; CONN-3.81MM-KF2EDG-6
J3V3, J5V0, J24V0: CONN-02-.100-VERT-HEADER; CONN-.100-2
J16: CONN-05X2-SHD; 2X5-SHROUDED
J17: CONN-20-2-84952-0; CON20_SMT-RA_FCC-FPC2
LED0, LED1, LED2, LED3: CONN-02-.100-VERT-HEADER; CONN-.100-2
Q2, Q3, Q4, Q5: FET-NCH-TO252; TO252
R1, R6, R7: 1k; R-0603
R2, R3, R4, R5: 220; R-0603
R8: 0; R-0603
R10, R11, R12, R14, R28: 100; R-0603
R13, R15, R29: 10k; R-0603
RESET: CONN-02-.100-VERT-HEADER; CONN-.100-2
U1: IO-MCP23017ML; QFN28-ML_6X6MM
U13: CONN-20-FPC-0.50MM-10051922-2010ELF; FCI_10051922-2010ELF
USER0, USER1, USER2, USER3: CONN-02-.100-VERT-HEADER; CONN-.100-2

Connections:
3V3: C1.1, J3V3.2, J16.1, J17.1, J17.17, J17.18, R1.2, R6.2, R7.2, R8.1, R13.2, R15.2, R29.2, U1.5 (VDD), U13.5, U13.20; also elsewhere on the board
5V0: I2C.2, J5V0.2; also elsewhere on the board
24V0: D3.C, D4.C, D5.C, D6.C, J2.6, J24V0.2; also elsewhere on the board
AUDIO: AUDIO.1, J16.9, J17.9, U13.11
CS_DISPLAY: J16.6, J17.6, U13.15
CYCLE_START: R14.2; also elsewhere on the board
DISPLAY_CS: U1.21 (GPA4)
DISPLAY_DC: U1.22 (GPA5)
ESTOP: ESTOP.2, R28.1, R29.1; also elsewhere on the board
FEED_HOLD: R12.2; also elsewhere on the board
GND: C1.2, C2.1, C3.2, C5.2, C8.2, C12.2, CYCLE.1, ESTOP.1, FEED.1, I2C.1, J2.1, J3V3.1, J5V0.1, J16.2, J16.10, J17.2, J17.19, J17.20, J24V0.1, LED0.1, LED1.1, LED2.1, LED3.1, Q2.2 (S), Q3.2 (S), Q4.2 (S), Q5.2 (S), RESET.1, U1.6 (VSS), U1.11 (A0), U1.12 (A1), U1.13 (A2), U13.1, U13.2, U13.6, U13.19, U13.G1 (G), U13.G2 (G), USER0.1, USER1.1, USER2.1, USER3.1; also elsewhere on the board
INT_DISPLAY: J16.7, J17.7, U13.14
MISO: J16.4, J17.4, U13.17; also elsewhere on the board
MOSI: J16.5, J17.5, U13.16; also elsewhere on the board
unnamed: R5.1, U1.17 (GPA0)
unnamed: R4.1, U1.18 (GPA1)
unnamed: FEED.2, R12.1, R13.1
unnamed: CYCLE.2, R14.1, R15.1
unnamed: I2C.4, R1.1, R10.1
unnamed: I2C.3, R7.1, R11.1
unnamed: D6.A, J2.2, Q5.3 (D)
unnamed: R3.1, U1.19 (GPA2)
unnamed: R2.1, U1.20 (GPA3)
unnamed: LED3.2, R2.2
unnamed: LED2.2, R3.2
unnamed: LED1.2, R4.2
unnamed: LED0.2, R5.2
unnamed: D5.A, J2.3, Q4.3 (D)
unnamed: D4.A, J2.4, Q3.3 (D)
unnamed: D3.A, J2.5, Q2.3 (D)
unnamed: Q2.1 (G), U1.1 (GPB4)
unnamed: Q3.1 (G), U1.2 (GPB5)
unnamed: Q4.1 (G), U1.3 (GPB6)
unnamed: Q5.1 (G), U1.4 (GPB7)
unnamed: R8.2, U13.3, U13.4
PD_DISPLAY: J16.8, J17.8, U13.13
RESET: C2.2, R6.1, RESET.2, U1.14 (!RESET); also elsewhere on the board
SCK: J16.3, J17.3, U13.18; also elsewhere on the board
SCL: R10.2, U1.8 (SCL); also elsewhere on the board
SDA: R11.2, U1.9 (SDA); also elsewhere on the board
USER0: C3.1, U1.25 (GPB0), USER0.2
USER1: C5.1, U1.26 (GPB1), USER1.2
USER2: C8.1, U1.27 (GPB2), USER2.2
USER3: C12.1, U1.28 (GPB3), USER3.2

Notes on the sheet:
Matrix Orbital EVE2-70G-TPC FFC 20P-0.5mm bottom connector flipped 1-20, 2-19, etc
New Haven NHD-7.0-800480FT-CSXV-CTP FFC 20P-1.0mm top
1 2 3 4 5 6 7 8 9 10 11 12 13 14 15 16 17 18 19 20
flyback

Board: 2 copper layers, 152 parts (0 on the bottom side), 116 nets, no tracks yet.

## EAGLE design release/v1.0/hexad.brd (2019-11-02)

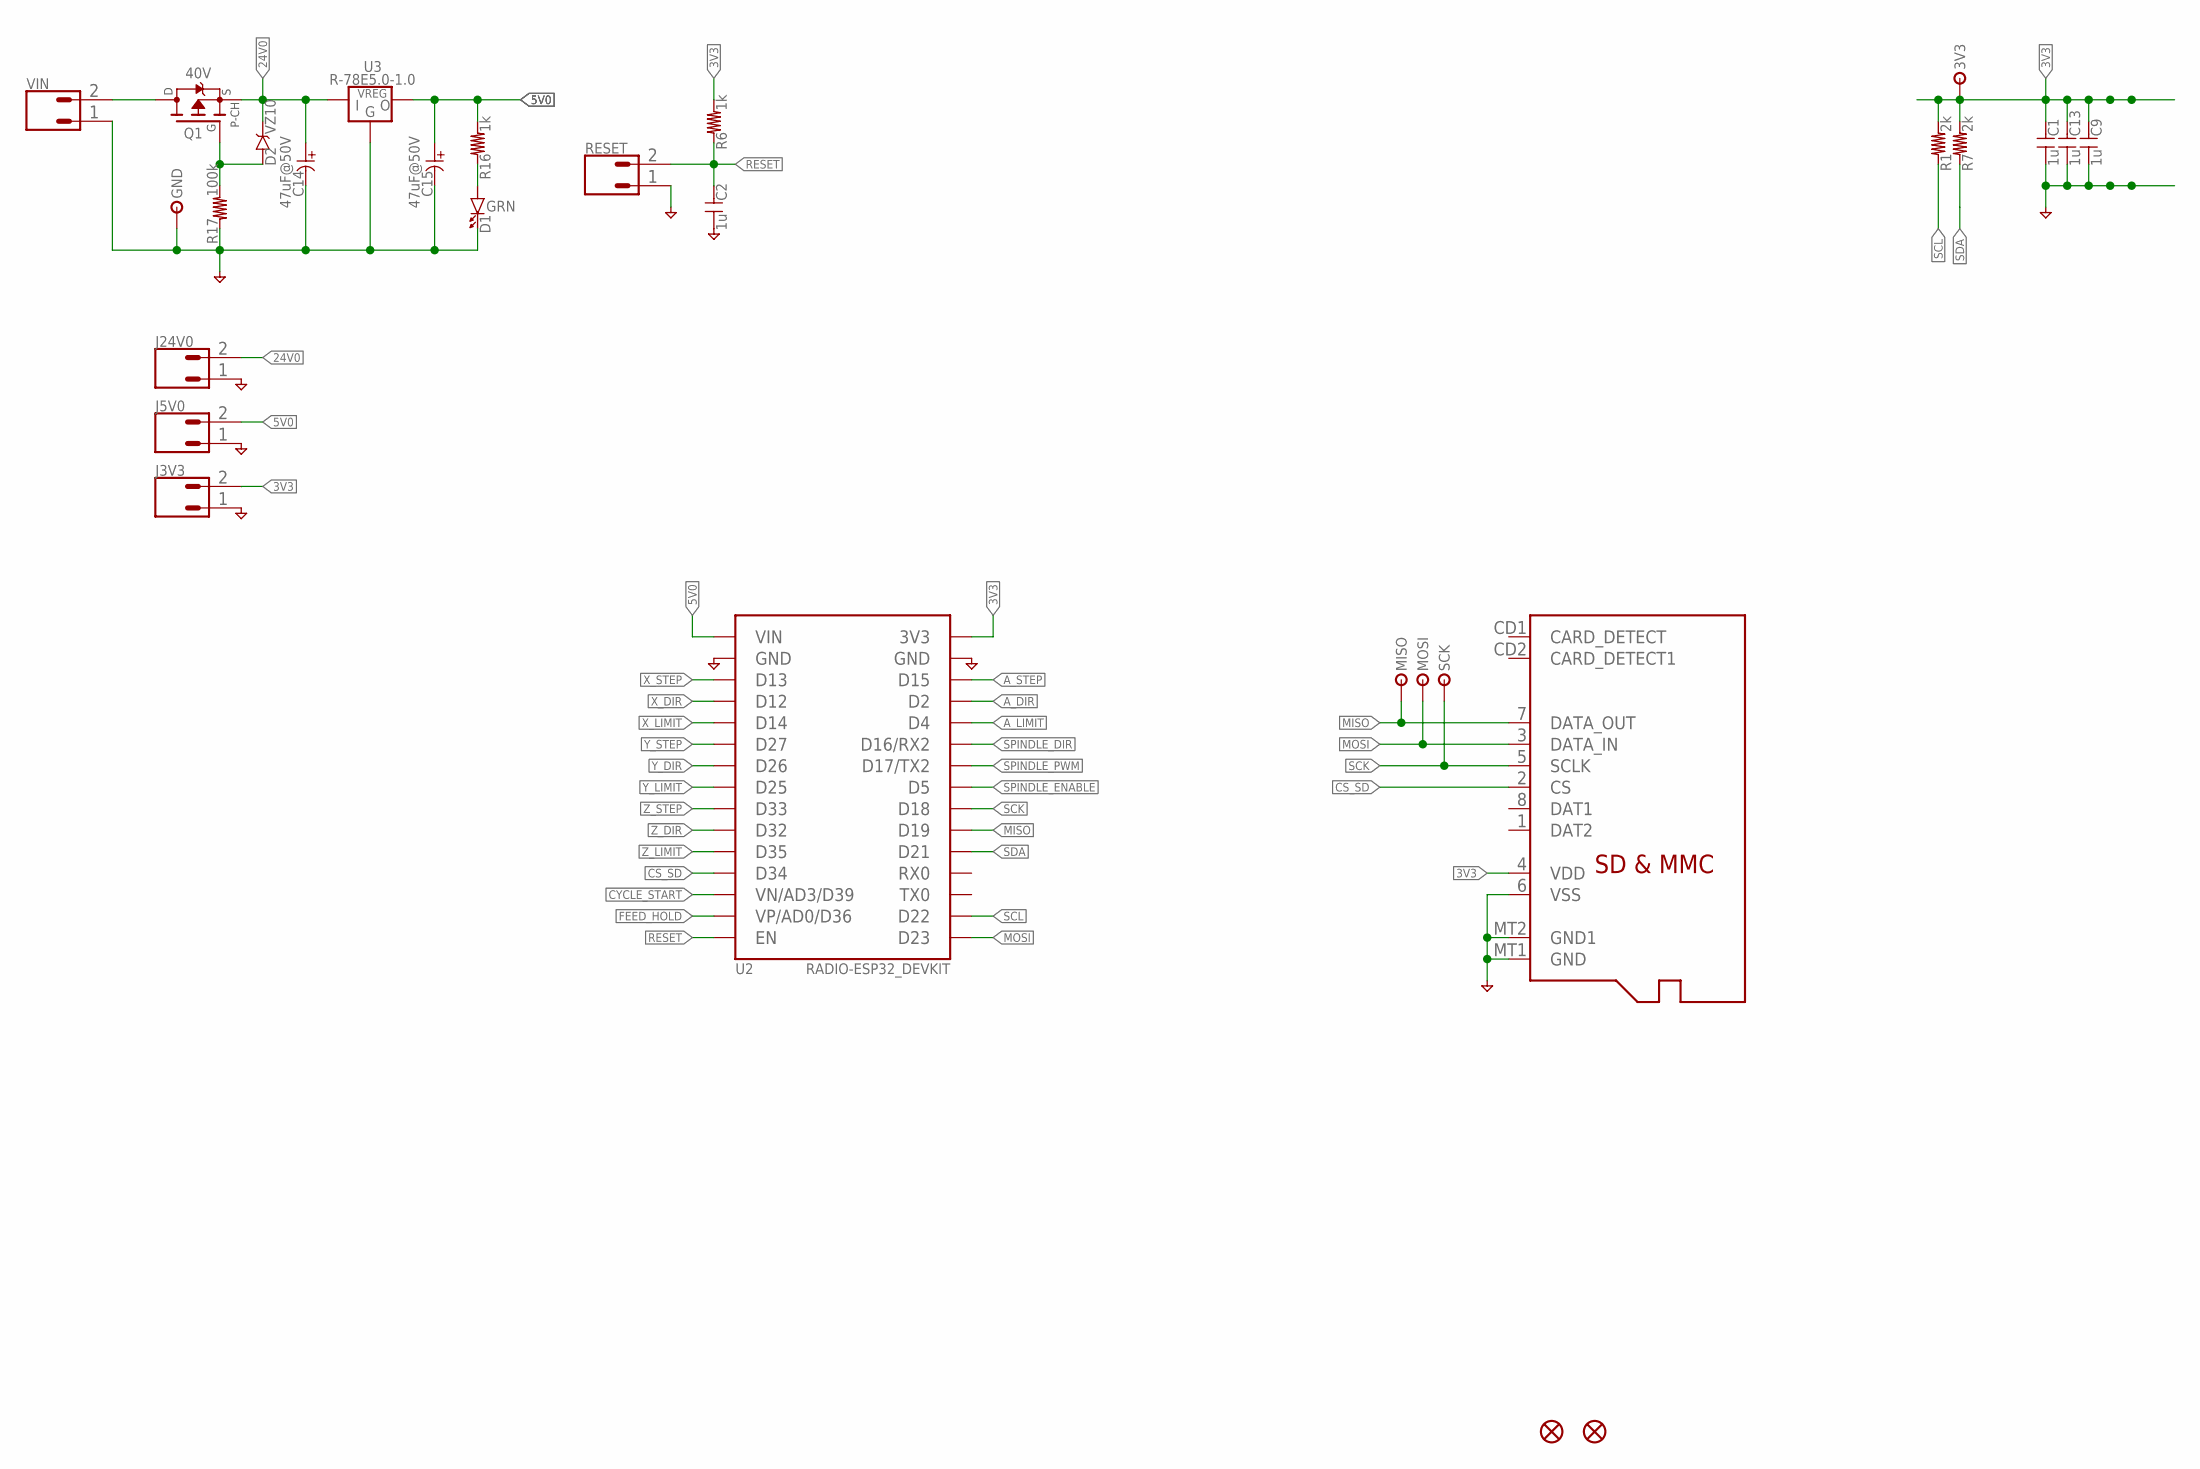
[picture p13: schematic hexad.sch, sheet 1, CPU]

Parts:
3V3: TESTPOINTTHRU; TPTHRU
C1, C2, C9, C13: 1u; C-0603
C14, C15: 47uF@50V; C-E-6
D1: GRN; LED-0603
D2: VZ10; D-SOD323
FID1, FID2: FIDUCIAL-MICRO
GND: TESTPOINTTHRU; TPTHRU
J1: CONN-MICROSD-2908-05WB-MG
J3V3, J5V0, J24V0: CONN-02-.100-VERT-HEADER; CONN-.100-2
MISO: TESTPOINTTHRU; TPTHRU
MOSI: TESTPOINTTHRU; TPTHRU
Q1: 40V; TO252
R1, R7: 2k; R-0603
R6, R16: 1k; R-0603
R17: 100k; R-0603
RESET: CONN-02-.100-VERT-HEADER; CONN-.100-2
SCK: TESTPOINTTHRU; TPTHRU
U2: RADIO-ESP32_DEVKIT; ESP32_DEVKIT
U3: R-78E5.0-1.0; VREG-SIP3
VIN: CONN-02-3.81MM-PLUGIN-SCREW; CONN-3.81MM-KF2EDG-2

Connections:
3V3: 3V3.1, C1.2, C9.2, C13.2, J1.4 (VDD), J3V3.2, R1.2, R6.2, R7.2, U2.3V3; also elsewhere on the board
5V0: C15.+, J5V0.2, R16.2, U2.VIN, U3.3 (VOUT); also elsewhere on the board
24V0: C14.+, D2.C, J24V0.2, Q1.2 (S), U3.1 (VIN); also elsewhere on the board
A_DIR: U2.D2; also elsewhere on the board
A_LIMIT: U2.D4; also elsewhere on the board
A_STEP: U2.D15; also elsewhere on the board
CS_SD: J1.2 (CS), U2.D34
CYCLE_START: U2.VN (VN/AD3/D39); also elsewhere on the board
FEED_HOLD: U2.VP (VP/AD0/D36); also elsewhere on the board
GND: C1.1, C2.1, C9.1, C13.1, C14.-, C15.-, D1.C, GND.1, J1.6 (VSS), J1.MT1 (GND), J1.MT2 (GND1), J3V3.1, J5V0.1, J24V0.1, R17.1, RESET.1, U2.GND@1 (GND), U2.GND@2 (GND), U3.2 (GND), VIN.1; also elsewhere on the board
MISO: J1.7 (DATA_OUT), MISO.1, U2.D19
MOSI: J1.3 (DATA_IN), MOSI.1, U2.D23; also elsewhere on the board
unnamed: Q1.3 (D), VIN.2
unnamed: D2.A, Q1.1 (G), R17.2
unnamed: D1.A, R16.1
RESET: C2.2, R6.1, RESET.2, U2.EN; also elsewhere on the board
SCK: J1.5 (SCLK), SCK.1, U2.D18; also elsewhere on the board
SCL: R1.1, U2.D22; also elsewhere on the board
SDA: R7.1, U2.D21; also elsewhere on the board
SPINDLE_DIR: U2.RX2 (D16/RX2); also elsewhere on the board
SPINDLE_ENABLE: U2.D5; also elsewhere on the board
SPINDLE_PWM: U2.TX2 (D17/TX2); also elsewhere on the board
X_DIR: U2.D12; also elsewhere on the board
X_LIMIT: U2.D14; also elsewhere on the board
X_STEP: U2.D13; also elsewhere on the board
Y_DIR: U2.D26; also elsewhere on the board
Y_LIMIT: U2.D25; also elsewhere on the board
Y_STEP: U2.D27; also elsewhere on the board
Z_DIR: U2.D32; also elsewhere on the board
Z_LIMIT: U2.D35; also elsewhere on the board
Z_STEP: U2.D33; also elsewhere on the board

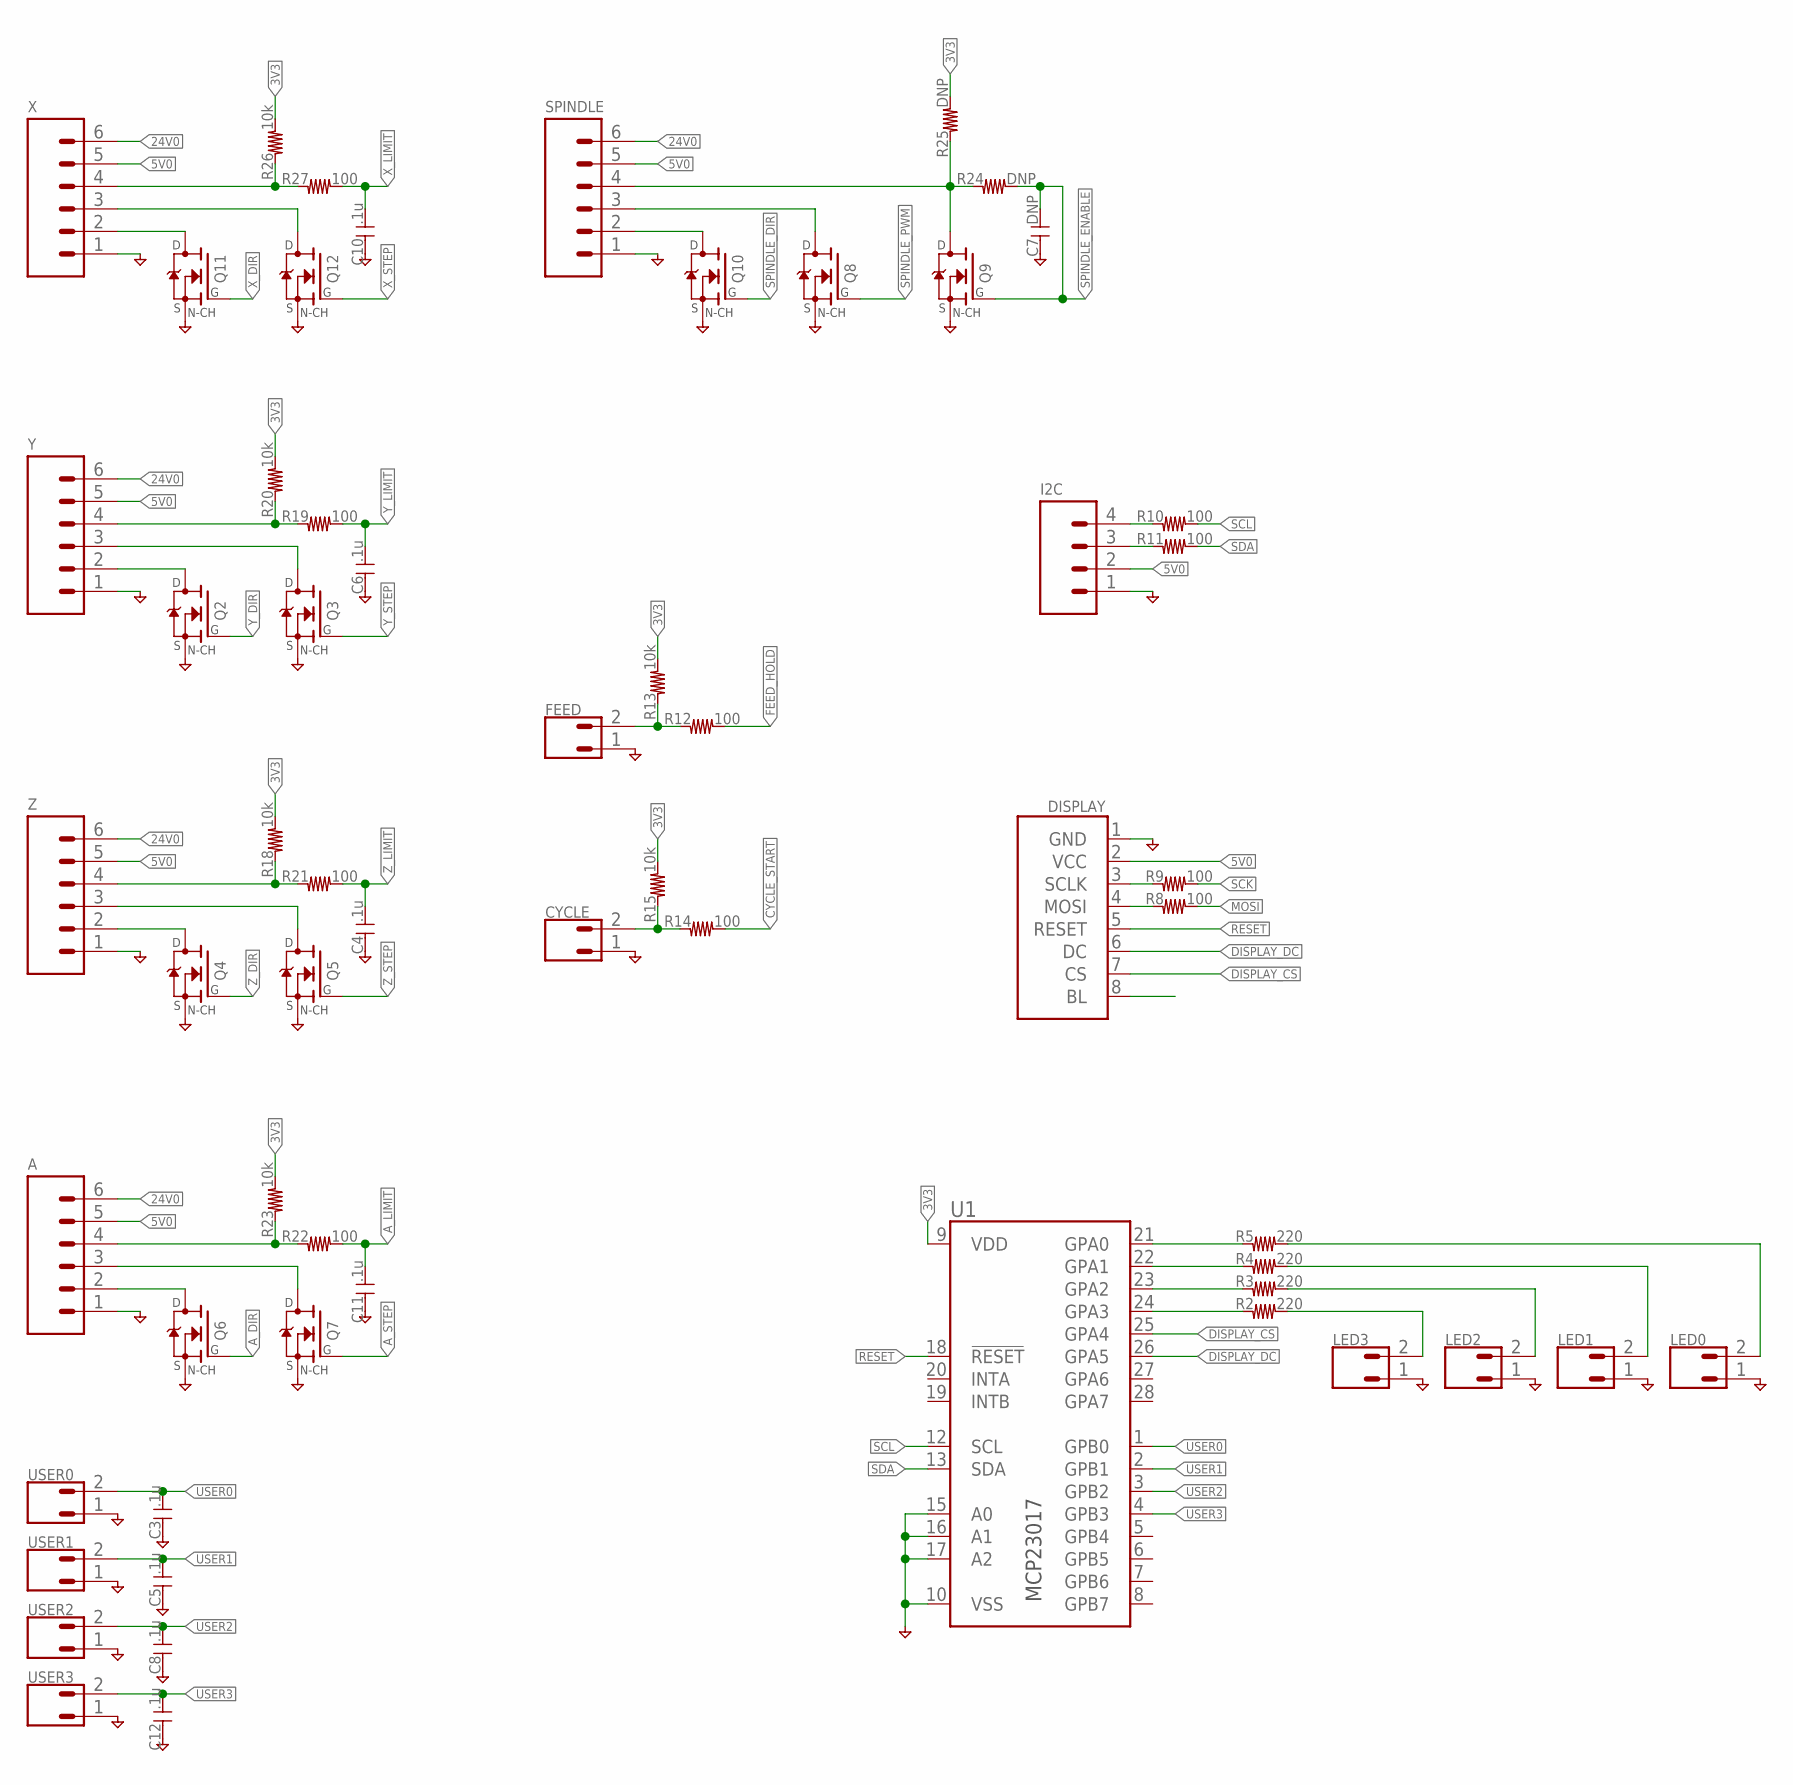
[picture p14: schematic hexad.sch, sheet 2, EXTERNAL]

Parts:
A: CONN-06-.100-VERT-HEADER; CONN-.100-6
C3, C4, C5, C6, C8, C10, C11, C12: .1u; C-0603
C7: DNP; C-0603
CYCLE: CONN-02-.100-VERT-HEADER; CONN-.100-2
DISPLAY: DISP-SPI-TFT-128X160-ST7735; 1X08
FEED: CONN-02-.100-VERT-HEADER; CONN-.100-2
I2C: CONN-04-.100-VERT-HEADER; CONN-.100-4
LED0, LED1, LED2, LED3: CONN-02-.100-VERT-HEADER; CONN-.100-2
Q2, Q3, Q4, Q5, Q6, Q7, Q8, Q9, Q10, Q11, Q12: FET-NCH-SOT23; SOT23-3
R2, R3, R4, R5: 220; R-0603
R8, R9, R10, R11, R12, R14, R19, R21, R22, R27: 100; R-0603
R13, R15, R18, R20, R23, R26: 10k; R-0603
R24, R25: DNP; R-0603
SPINDLE: CONN-06-.100-VERT-HEADER; CONN-.100-6
U1: IO-MCP23017SO; SO28W
USER0, USER1, USER2, USER3: CONN-02-.100-VERT-HEADER; CONN-.100-2
X: CONN-06-.100-VERT-HEADER; CONN-.100-6
Y: CONN-06-.100-VERT-HEADER; CONN-.100-6
Z: CONN-06-.100-VERT-HEADER; CONN-.100-6

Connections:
3V3: R13.2, R15.2, R18.2, R20.2, R23.2, R25.2, R26.2, U1.9 (VDD); also elsewhere on the board
5V0: A.5, DISPLAY.2 (VCC), I2C.2, SPINDLE.5, X.5, Y.5, Z.5; also elsewhere on the board
24V0: A.6, SPINDLE.6, X.6, Y.6, Z.6; also elsewhere on the board
A_DIR: Q6.1 (G); also elsewhere on the board
A_LIMIT: C11.1, R22.2; also elsewhere on the board
A_STEP: Q7.1 (G); also elsewhere on the board
CYCLE_START: R14.2; also elsewhere on the board
DISPLAY_CS: DISPLAY.7 (CS), U1.25 (GPA4)
DISPLAY_DC: DISPLAY.6 (DC), U1.26 (GPA5)
FEED_HOLD: R12.2; also elsewhere on the board
GND: A.1, C3.2, C4.2, C5.2, C6.2, C7.2, C8.2, C10.2, C11.2, C12.2, CYCLE.1, DISPLAY.1 (GND), FEED.1, I2C.1, LED0.1, LED1.1, LED2.1, LED3.1, Q2.2 (S), Q3.2 (S), Q4.2 (S), Q5.2 (S), Q6.2 (S), Q7.2 (S), Q8.2 (S), Q9.2 (S), Q10.2 (S), Q11.2 (S), Q12.2 (S), SPINDLE.1, U1.10 (VSS), U1.15 (A0), U1.16 (A1), U1.17 (A2), USER0.1, USER1.1, USER2.1, USER3.1, X.1, Y.1, Z.1; also elsewhere on the board
MOSI: R8.2; also elsewhere on the board
unnamed: R26.1, R27.1, X.4
unnamed: DISPLAY.3 (SCLK), R9.1
unnamed: DISPLAY.4 (MOSI), R8.1
unnamed: Q11.3 (D), X.2
unnamed: R19.1, R20.1, Y.4
unnamed: Q2.3 (D), Y.2
unnamed: R18.1, R21.1, Z.4
unnamed: Q4.3 (D), Z.2
unnamed: A.4, R22.1, R23.1
unnamed: A.2, Q6.3 (D)
unnamed: R5.1, U1.21 (GPA0)
unnamed: Q9.3 (D), R24.1, R25.1, SPINDLE.4
unnamed: Q10.3 (D), SPINDLE.2
unnamed: R4.1, U1.22 (GPA1)
unnamed: FEED.2, R12.1, R13.1
unnamed: CYCLE.2, R14.1, R15.1
unnamed: I2C.4, R10.1
unnamed: I2C.3, R11.1
unnamed: R3.1, U1.23 (GPA2)
unnamed: R2.1, U1.24 (GPA3)
unnamed: LED3.2, R2.2
unnamed: LED2.2, R3.2
unnamed: LED1.2, R4.2
unnamed: LED0.2, R5.2
RESET: DISPLAY.5 (RESET), U1.18 (!RESET); also elsewhere on the board
SCK: R9.2; also elsewhere on the board
SCL: R10.2, U1.12 (SCL); also elsewhere on the board
SDA: R11.2, U1.13 (SDA); also elsewhere on the board
SPINDLE_DIR: Q10.1 (G); also elsewhere on the board
SPINDLE_ENABLE: C7.1, Q9.1 (G), R24.2; also elsewhere on the board
SPINDLE_PWM: Q8.1 (G); also elsewhere on the board
USER0: C3.1, U1.1 (GPB0), USER0.2
USER1: C5.1, U1.2 (GPB1), USER1.2
USER2: C8.1, U1.3 (GPB2), USER2.2
USER3: C12.1, U1.4 (GPB3), USER3.2
X_DIR: Q11.1 (G); also elsewhere on the board
X_LIMIT: C10.1, R27.2; also elsewhere on the board
X_STEP: Q12.1 (G); also elsewhere on the board
X_STEP_5V0: Q12.3 (D), X.3
X_STEP_5V1: Q3.3 (D), Y.3
X_STEP_5V2: Q5.3 (D), Z.3
X_STEP_5V3: A.3, Q7.3 (D)
X_STEP_5V4: Q8.3 (D), SPINDLE.3
Y_DIR: Q2.1 (G); also elsewhere on the board
Y_LIMIT: C6.1, R19.2; also elsewhere on the board
Y_STEP: Q3.1 (G); also elsewhere on the board
Z_DIR: Q4.1 (G); also elsewhere on the board
Z_LIMIT: C4.1, R21.2; also elsewhere on the board
Z_STEP: Q5.1 (G); also elsewhere on the board

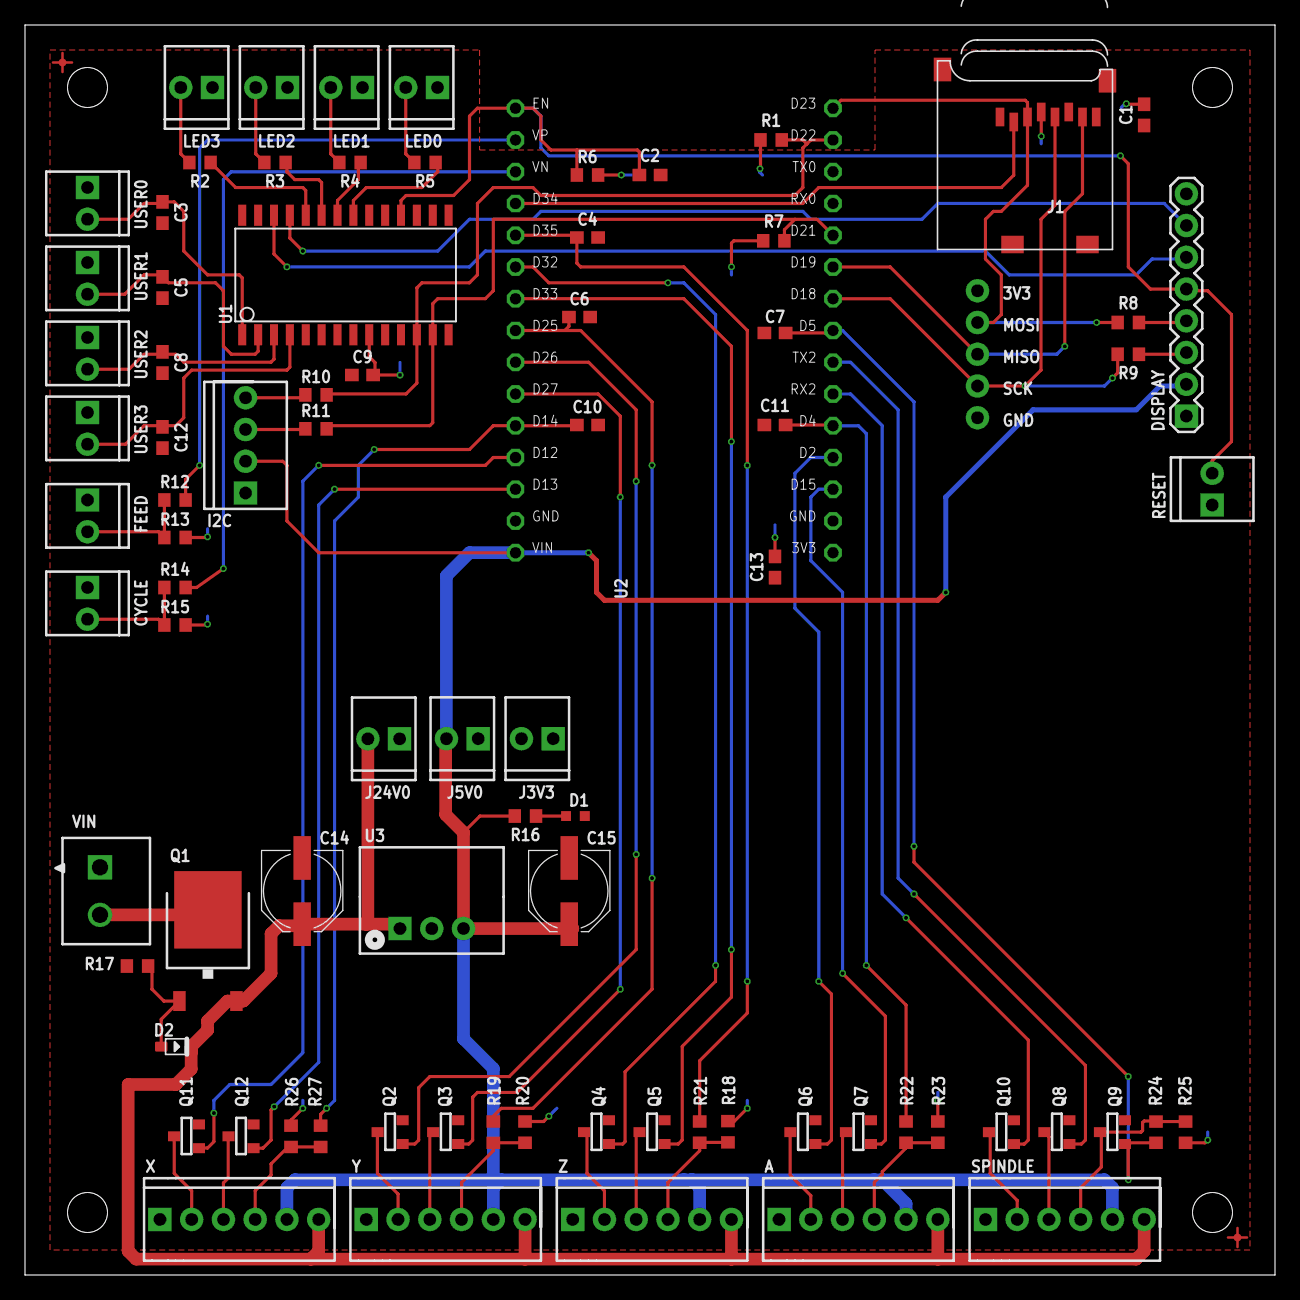
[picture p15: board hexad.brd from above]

Board: 2 copper layers, 100.0 x 100.0 mm, 89 parts (0 on the bottom side), 66 nets.

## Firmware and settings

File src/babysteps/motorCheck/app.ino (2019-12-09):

// this doesn't work

#define STEP GPIO_NUM_33
#define DIR  GPIO_NUM_32

int i;
 
void setup() {
  pinMode(STEP,OUTPUT);
  pinMode(DIR, OUTPUT);
  delay(100);
  digitalWrite(DIR,LOW);
  digitalWrite(STEP,LOW);
}
 
void loop() {
  for (i = 0; i < 5000;i++) {
    digitalWrite(STEP,HIGH);
    delayMicroseconds(10);
    digitalWrite(STEP,LOW);
    delayMicroseconds(1000);
  }
  delay(1000);
}

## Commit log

2019-11-01 initial add
    [hexad.brd]
2019-11-01 added more parts
    [hexad.brd, hexad.sch]
2019-11-01 started routing
    [hexad.brd, hexad.sch]
2019-11-01 changed connectors to 0.1 headers
    [hexad.brd, hexad.sch]
2019-11-02 release v1.0
    [hexad.brd, hexad.sch]
2019-11-12 added todo to schematic
    [hexad.sch]
2019-11-12 moved a few things around on the schematic
    [hexad.brd, hexad.sch]
2019-11-13 started work on v1.1
    [tetrad.brd, tetrad.sch]
2019-11-18 updated schematic
    [tetrad.brd, tetrad.sch]
2019-11-18 started fixing board mistakes
    [tetrad.brd, tetrad.sch]
2019-11-18 beefed up 24v0 traces
    [tetrad.brd, tetrad.sch]
2019-11-20 starting add drv8825 slots and micro-fit connectors
    [tetrad.brd, tetrad.sch]
2019-11-23 selected hammond enclosure and larger board
    [tetrad.brd, tetrad.sch]
2019-11-23 started initial positioning
    [tetrad.brd, tetrad.sch]
2019-11-24 started placement of X
    [tetrad.brd, tetrad.sch]
2019-11-24 continued working on placement
    [tetrad.brd, tetrad.sch]
2019-12-09 XYZ tested # Please enter the commit message for your changes. Lines starting
    [hexad.brd, hexad.sch, tetrad.brd]
2019-12-21 x,y,z,a hardware checked out
    [tetrad.sch]
2019-12-21 checked out the spindle hardware started to simplify the motor part of schematic
    [tetrad.brd, tetrad.sch]
2020-02-02 schematic updated alot moving to bud PN-1325-DGMB enclosure initial add for others
    [tetrad.brd, tetrad.sch]
